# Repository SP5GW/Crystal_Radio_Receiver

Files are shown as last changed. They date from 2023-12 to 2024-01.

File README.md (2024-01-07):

# Crystal Radio Receiver

<p align="center">
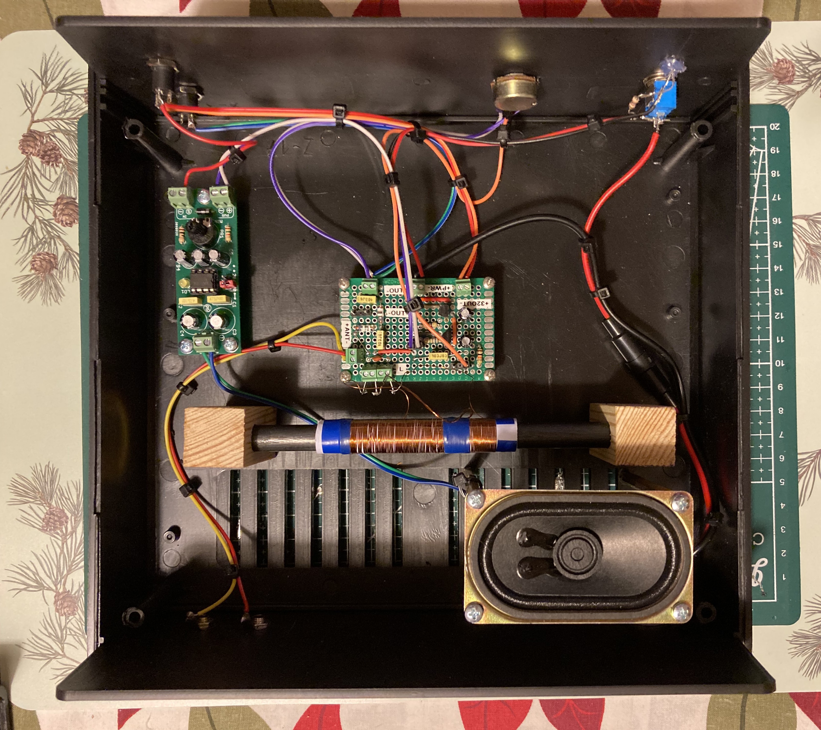
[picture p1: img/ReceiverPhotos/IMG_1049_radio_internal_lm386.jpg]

</p> 

## Design Overview

Implementation of crystal radio in its simplest form does not include active amplifier and that is why can function without external power supply. 

<p align="center">
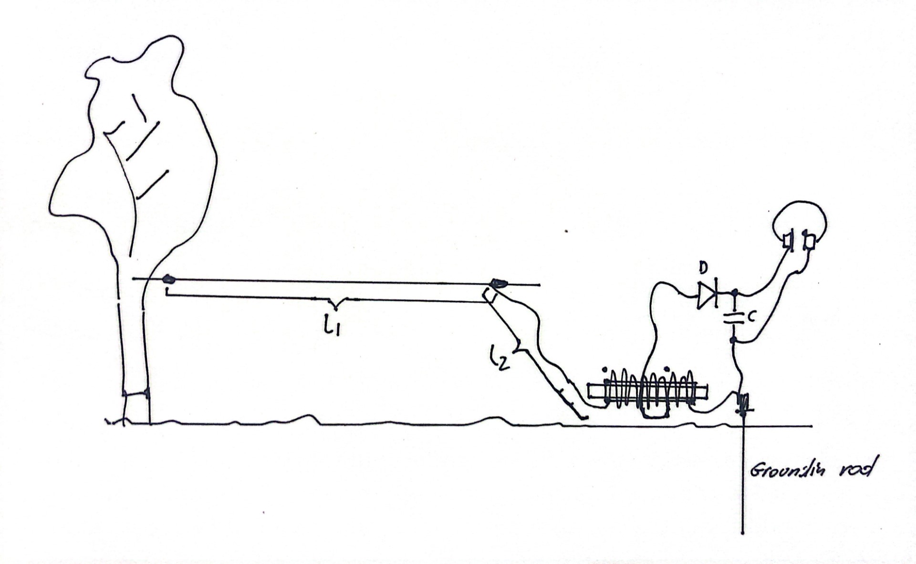
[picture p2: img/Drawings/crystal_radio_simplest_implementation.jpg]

</p>

There are three building blocks of such radio: bandpass filter based on RLC circuit, detector/demodulator stage and high impedance headphones (common today 32ohm headphones can be used as well, but would require amplification stage).

<p align="center">
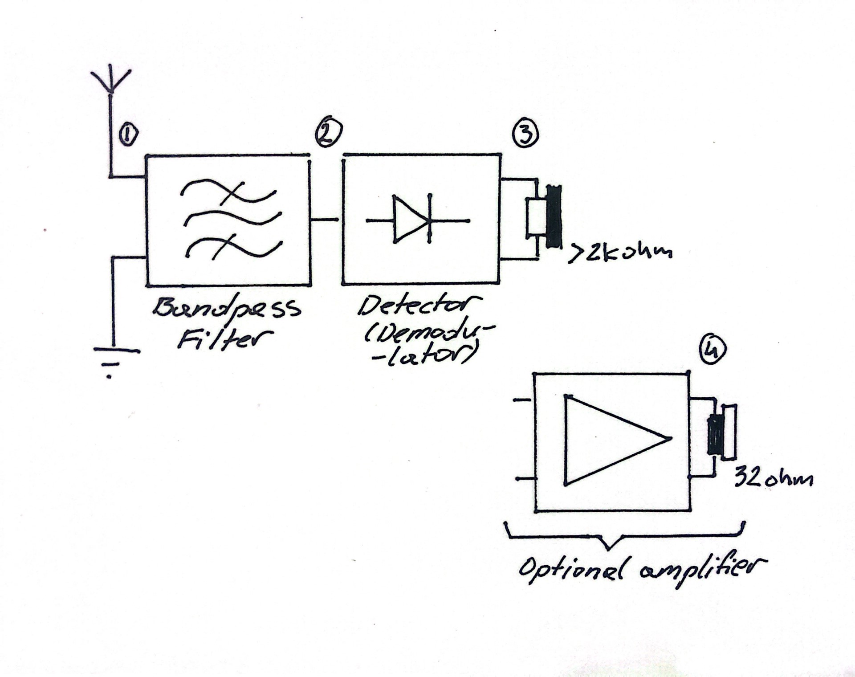
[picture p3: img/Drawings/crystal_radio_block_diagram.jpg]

</p>

Contrary to common believe that crystal radio unit always include RLC parallel resonant circuit, design described here is based on serial resonant RLC circuit consisting of random wire antenna and the coil. Random wire antenna provides capacitance required to form together with the coil serial LC resonant circuit. 

To decrease impact of relatively low detector stage impedance on quality Q of LC circuit, tapped coil is used (autotransformer configuration). 
In ealry designs both tap and also coil itself was often skipped. In such implementation signal level reaching detector stage would be higher (assuming detector input impedance will be higher then the one of coil), but there will be very poor or no selectivity. 

Compromise between output signal strenth and selectivity is a main challange of crystal radio design. 

In discussed circuit, crystal has been replaced with germanium diode. Half-wave rectifier has been also replaced with full rectifier configuration in actual implementation. This however did not lead to any improvments in signal quality or strength since benefit of increased output voltage has been ofsetted by incresed load (x2) put by this type of rectifier on the coil compared to its half wave variant. This is the reason for leaving half wave recifier on all drawings mentioned in this section.

Experiments were made with use of more common Shotkeys diodes, but were not successful (not possible to detect any signals).

Due to relatively high detector output impedance, the use of high impedance headphones or high input impedance amplifier stage is a must.

Capacitor C, which filters out carrier frequency from baseband signal has been left in the design, but its presence did not make any impact on output signal quality.

This type of crystal radio design requires unbalanced antenna i.e. grounding must be of high quality (resistance of 10-100ohm) in order for radio to operate.

Electronic circuit has been inspired by design described by Andrzej Dabrowski OE1KDA in Swiat Radio [1] / Issue 54 of Library of Polish HAM [2] and 
more recent work of Bob Culter N7FKI in ARRL QST magazine [9].

Theory of operation has been predicted during Spice simulations. Details of technical design are based on great work of Berthold Bosch, DK6YY  Crystal Set Analysis [5],  Kenneth A. Kuhn, Crystal Radio Engineering [7] and Johen Bauer, Receiving Antennas for the AM Bands = Loop vs. Vertical Wire [8].

## Design Details

As mentioned earlier in this particular implementation of crystal radio, antenna and the coil form the resonant serial RLC ciruit, which can be modelled as depicted on the drawing below:

<p align="center">
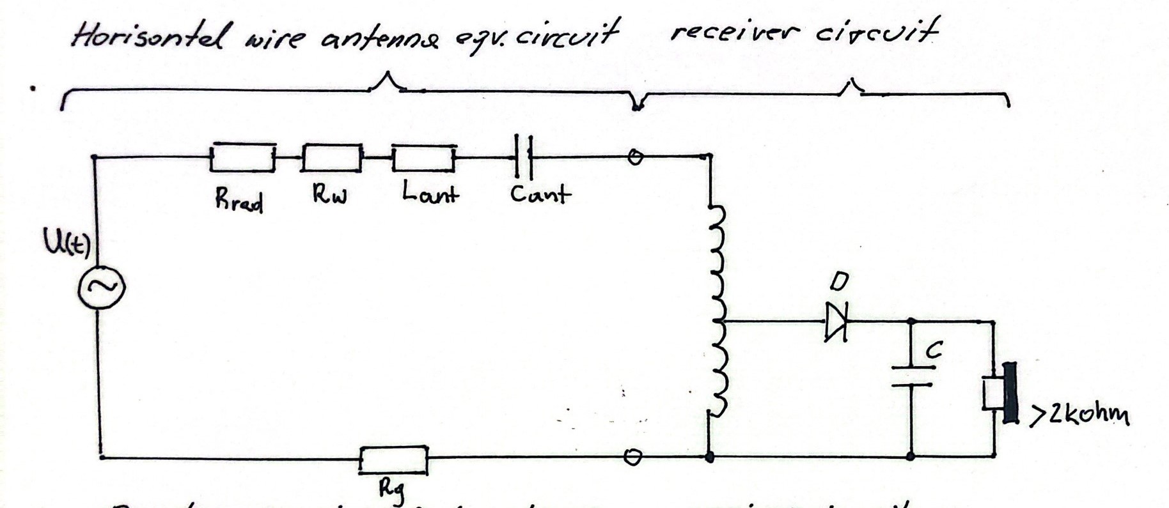
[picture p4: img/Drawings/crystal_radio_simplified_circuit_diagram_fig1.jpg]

</p>

where [7],[8]:
* 	**U(t)** - ideal voltage source - antenna voltage pickup
* 	**Cant** - antenna's serial capacitance - dominating part of antenna's 	reactance if the antenna is shorter than one-quarter wavelength
* 	**Lant** - antenna's serial inductance -  dominating part of antenna's reactance if antenna is  between one-quarter and one-half wavelength at      which capacitive reactance dominates. (at one quarter wavelength antenna is resistive) next quarter wavelength
* 	**Rrad** - The effective radiation resistance associated with the total antenna length. For electrically short antennas this may only be a few ohms but can rise to several tens of ohms as the antenna length approaches one quarter wavelength.
* 	**Rw**   - electrical resistance that is mainly due to the skin effect of the conductor (antenna wire) since the frequency is high
* 	**Rg**   - ground resistance

In case of random wire antenna for long wave reception, antenna's electrical length is typically much smaller then lambda/4 coresponding to received frequency.

In our case the target frequency is f = 225kHz (Polish Radio Warszawa I Broadcast) and coresponding wave length:

$lambda = vf* (c/f)$ 

where:
* **c**  - speed of light in free space: 299 792 458 m/s
* **vf** - velocity factor for cooper wire: 0.95 (radio wave travels in the wire 5% slower then in free space)
* **f**  - broadcast frequency

hence:

* lambda (free space) = 1332,4m (lambda/4=333,1)
* lambda (cooper wire) = 0.95 * 1332,4 = 1265,8m (lambda/4 = 316.5m)

So the total length of our antenna cable (including wire leading to the radio) is 25m, which is shorter then lambda/4 for both free space and cooper wire.

Above means that antenna's reactance is purly capacitive  and **Lant** can be omited from the simplified model of used antenna design.

Due to the short length of antenna cable, wire resistance **Rw** can also be skipped.

Radiation resistance **Rrad** for electrically short antennas is typically equal to a few ohms (**Rrad** can rise to several tens of ohms as the antenna length approaches one quarter wavelength).

According to the property of reciprocity every antenna can be used to both transmit and receive electromagnetic radiation. That is why, radiation resistance can be understood as equivalent ohmic resistor, which "disipates" power delivered from the transmitter to the antenna. Power disipated in this case leaves antenna in the form of electromagnetic radiation. [8]

Ground Resistance **Rg** is dominant in the model and can be less then 10 ohms in case of excellent grounding and up to 100ohms and more when grounding is poor.

Based on above analysis and actual measurements summarized in table below it becomes apparent that random wire antenna's equivalent circuit can be simplified to include only capacitance **Cant** and **Rant** equal to Rg + Rrad.

<p align="center">
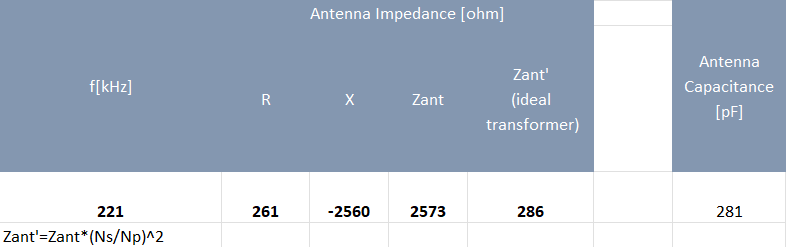
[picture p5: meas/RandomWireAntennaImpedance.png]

</p>

Equivalent circuit reflecting above assumptions:

<p align="center">
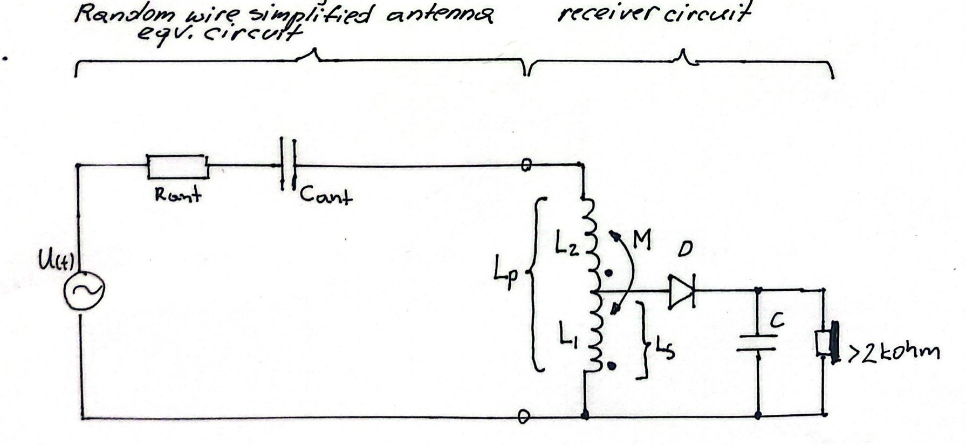
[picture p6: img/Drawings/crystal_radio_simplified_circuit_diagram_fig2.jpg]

</p>

The frequency of serial resonance for such circuit can be calculated as:

$fr=\frac{1}{2*\pi*\sqrt{Lp*Cant}}$

where **Lp** is the inductance of the coil expressed as:

$Lp=L1+L2+2M$

**Lp**, **L1** and **L2** can be directly measured with NanoVNA or another inductance meter while M can be calculated as:

$M=(Lp-L1-L2)/2$

For simulation purpuses it is useful to also calculate coupling coefficient **k** as:

$k=M/\sqrt{L1*L2}$

Actual measurements were summarized below:

<p align="center">
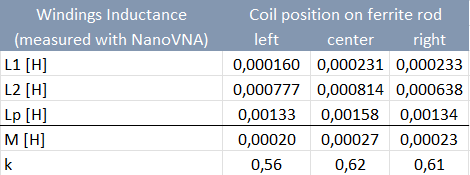
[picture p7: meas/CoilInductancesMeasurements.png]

</p>

As can be seen above, the tap on the coil does not impact resonance frequency, however level of magnetic coupling shall be taken into account when calculating inductance value of the coil i.e. total inductance is higher then the sum of inductances of each section of the coil measured separately.

For the coil centrally positioned on the ferrite rod resonance frequency is:

$fr=\frac{1}{6.28*\sqrt{1.58 \times 10^{-3} \times 281 \times 10^{-12}}}=238.72kHz$

It was not possible to increase coil's inductance **Lp** by repositioning it on the rod. That is why 47pF additional capacitor was added in parallel to **Lp** to bring resonance frequency **fr** to desired 225KHz. 
See Spice simulation below:

<p align="center">
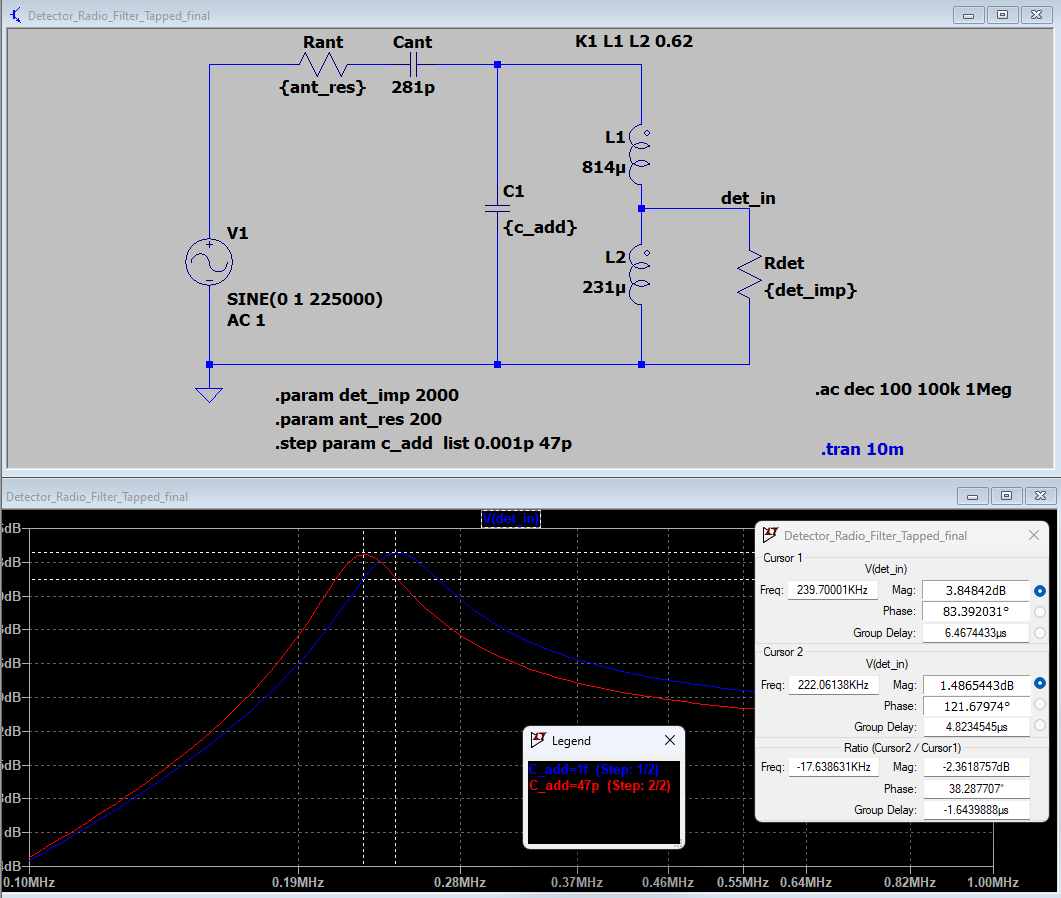
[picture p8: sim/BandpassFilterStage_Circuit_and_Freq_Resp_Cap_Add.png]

</p>

Input impedance of the detector stage together with antenna system resistance **Rant** directly impacts Q-factor of RLC resonance circuit.
This is the reason for both the need for best quality grounding (i.e. lowest possible **Rg**) 

<p align="center">
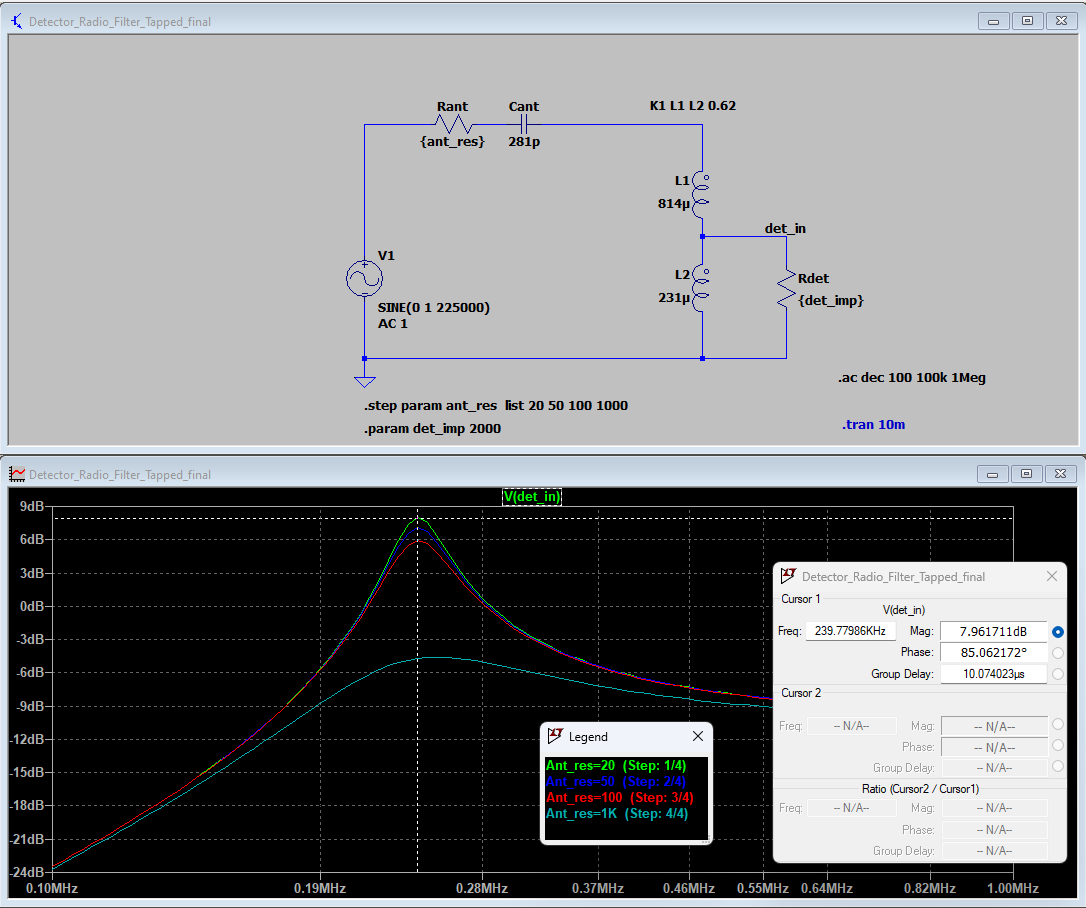
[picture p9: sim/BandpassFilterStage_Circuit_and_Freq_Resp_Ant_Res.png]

</p>

and also the use of autotransformer to connect detector stage to the RLC circuit.

<p align="center">
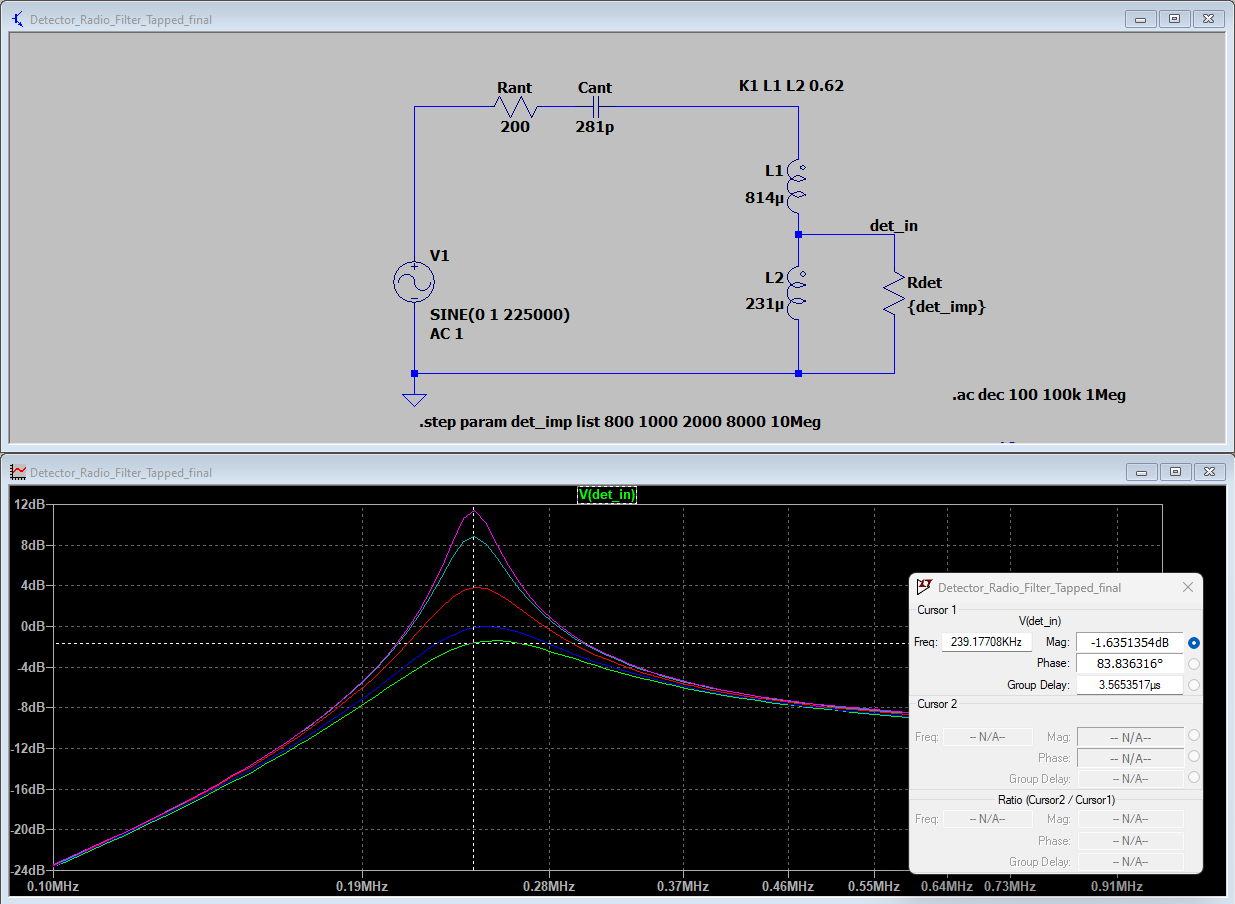
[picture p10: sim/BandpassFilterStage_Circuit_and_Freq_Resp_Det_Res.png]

</p>

Autotransformer transforms input impedance of the detector **Rdet** to larger value of **Rdet'**. In situation where reactace of **XL1** is much greater then **Rdet'** impedance transformation follows the formula for ideal transformer. 

$Rdet'/Rdet=N^2$ where $N=Np/Ns=sqrt(Lp/Ls)$

In case of this design however impedance transformation is "weakened" by the fact that **XL1**  is of similar value as transformed impedance of the detector stage (for fr=225kHz the impedance XL1=2.5kohm). For lower values of **Rdet**, detectors input impedance shounts also **XL1**, which also leads to slight shift upwords of the circuit's resonance frequency.

When detector stage is connected to the tap of the coil the RLC Q-factor decreases more then twice (i.e. decrease from 11.6 to 4.6), which coresponds to circuit's bandwidth increase from about 20kHz to 51kHz. This selectivity decrease makes design less dependent on exact value of antenna capacitance. 
As can be seen on the picture below the AM signal from Polish Radio occupies only about 12kHz in bandwidth (with center frequency fr=225Khz)

<p align="center">
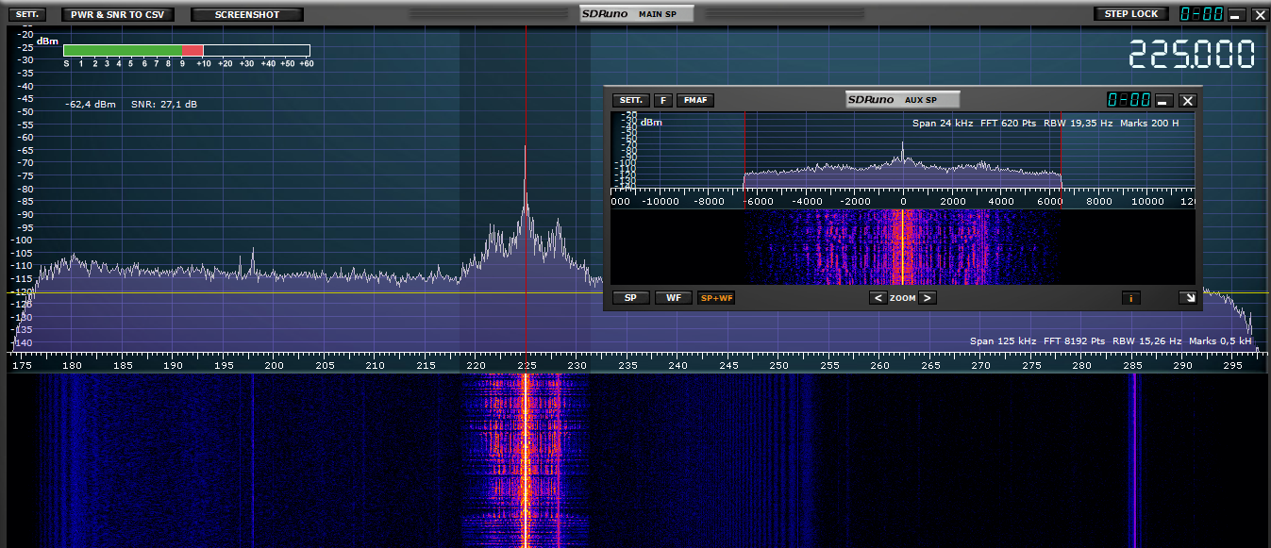
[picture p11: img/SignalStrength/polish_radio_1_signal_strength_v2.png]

</p>

As mentioned earlier attempt to replace Germanium AAP153 diode with Shotkey equivalent was not successful. 

Use of full wave rectifier in the design does not lead to increase signal volume compared to scenario when half wave rectifier is used. This is due to twice as low input impedance of full wave rectiver compared to its half wave variant.

When no external power source is available (aplifier based on T1/T2 is not used), high impedance headphones are needed. This is due high impedance of detector output.

Aplifier based on T1/T2 allows for use of regular 32ohm headphones, but this stage requires external power supply. To decrease amount high frequencies in signal reaching headphones RC low pass filter has been added in front of transistor aplification stage.

<p align="center">
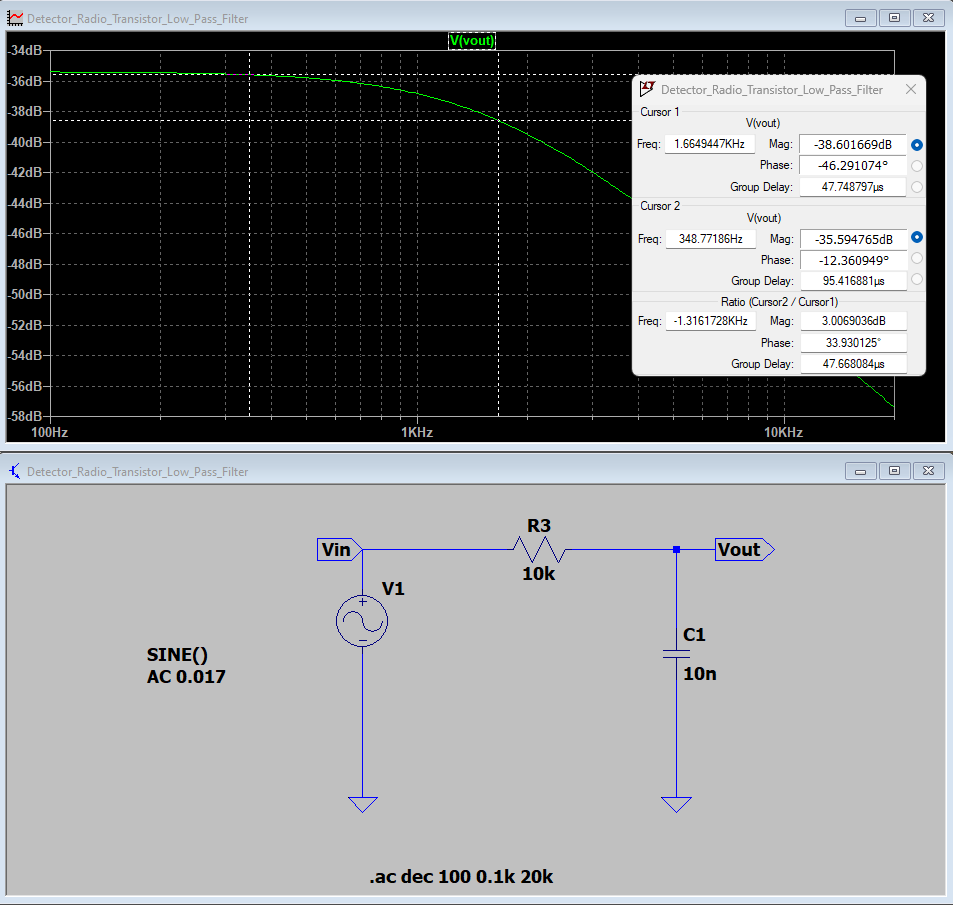
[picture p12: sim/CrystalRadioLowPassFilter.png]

</p>

Full Crystal Radio simulation circuit can be seen below:

<p align="center">
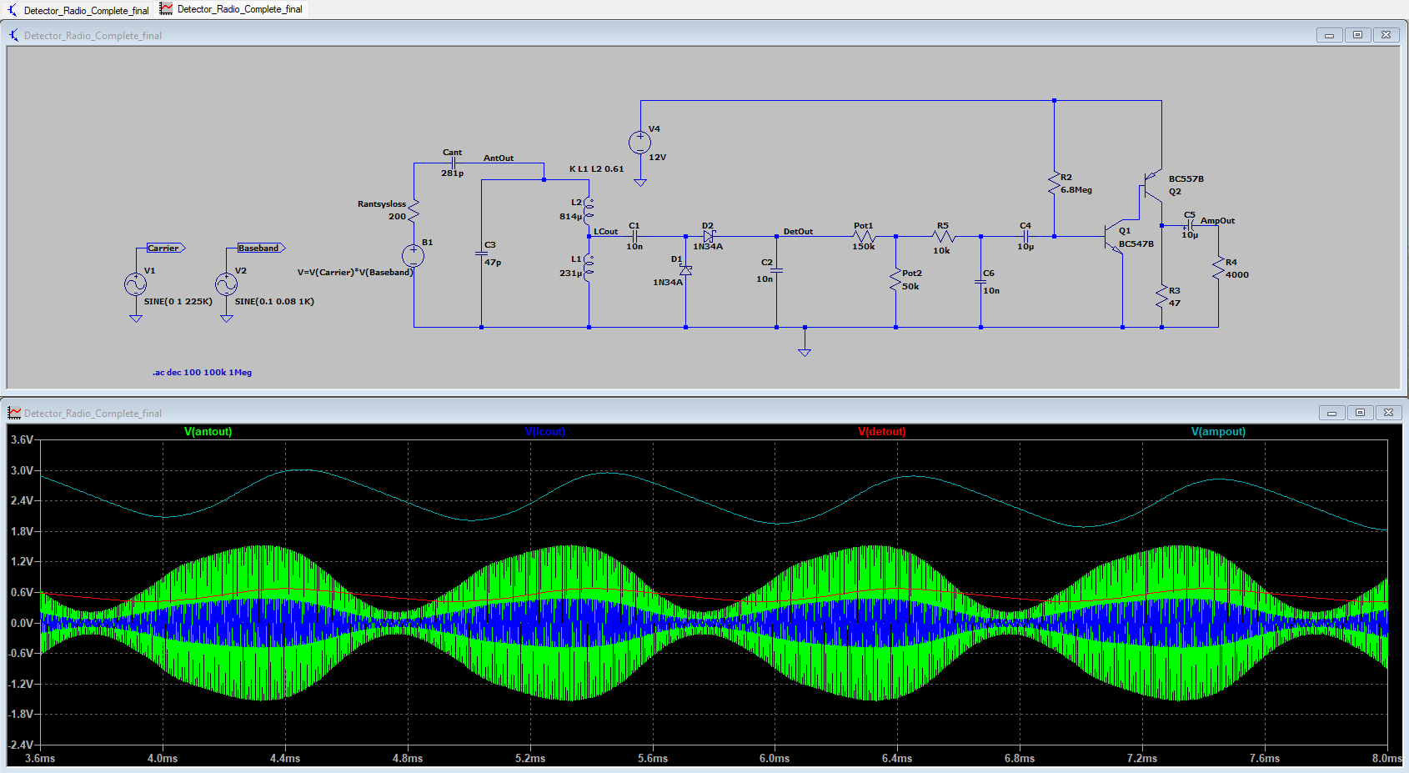
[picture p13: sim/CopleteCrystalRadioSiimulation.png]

</p>

## Implementation

<p align="center">
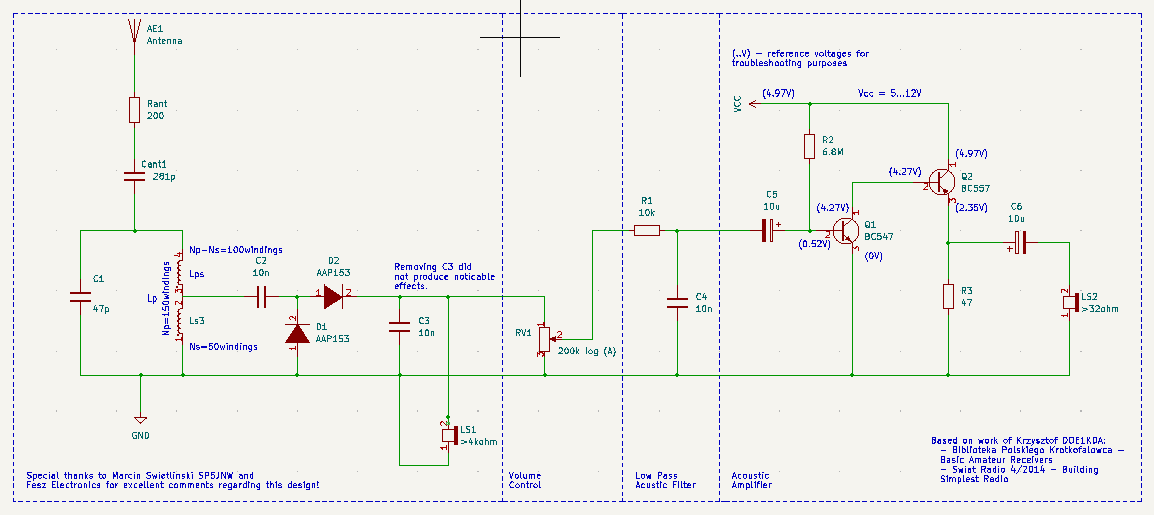
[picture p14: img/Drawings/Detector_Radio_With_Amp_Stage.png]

</p>

Design of the coil is critical for entire circuit to work. This element has been made using 0.35mm emalia coated wire. Windings were made on paper tube put on ferrite rod from old radio receiver. Position of the coil can be adjusted by sliding to both sides of the rod allowing for limited resonance frequency adjustment. Tuning is made by the ear for strongest acusting signal. Coil winding configuration: 50 windings - 5cm long tap - 100 windings. All windings are made in the same direction. To bring resonance frequency closer to 225kHz, the 47pF ceramic capacitor was put parallel to the coil. Decreasing this capacitor to smaller value did not increase signal level at detector output, capacitor increase led to decrease in volume, which suggest that selected capacitance value is optimal for this particular design.

Mechanical mounting of the coil can be difficult. The most elegant would be to 3D print required moutning brackets. In this case simpler wooden mounts were used purely due to lack 3D printer access. See pictures below for details of coil mounting method:

<p align="center">
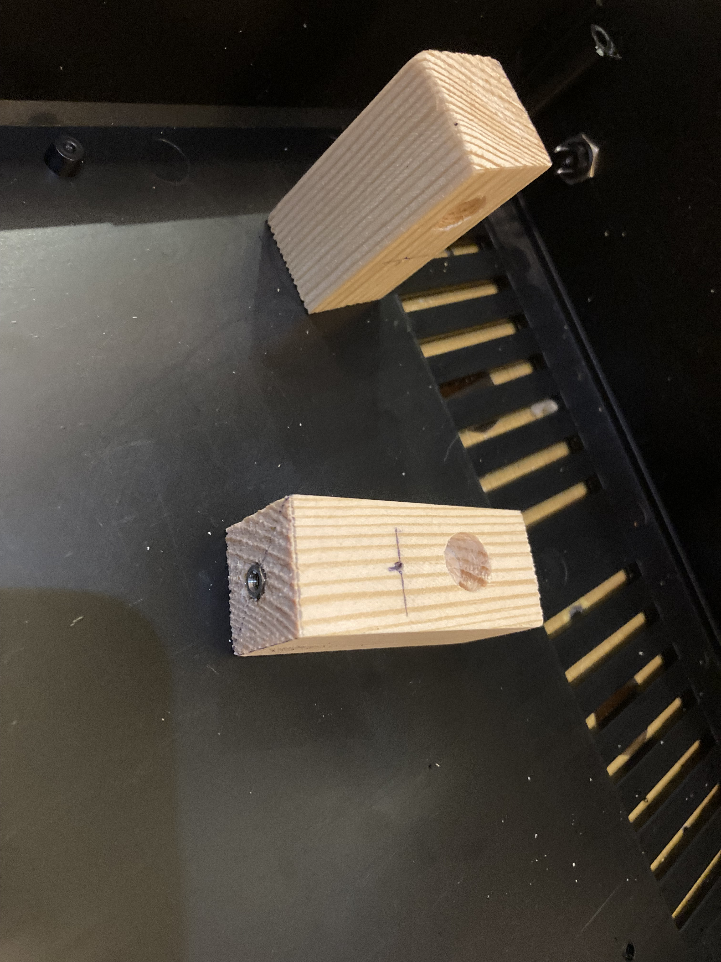
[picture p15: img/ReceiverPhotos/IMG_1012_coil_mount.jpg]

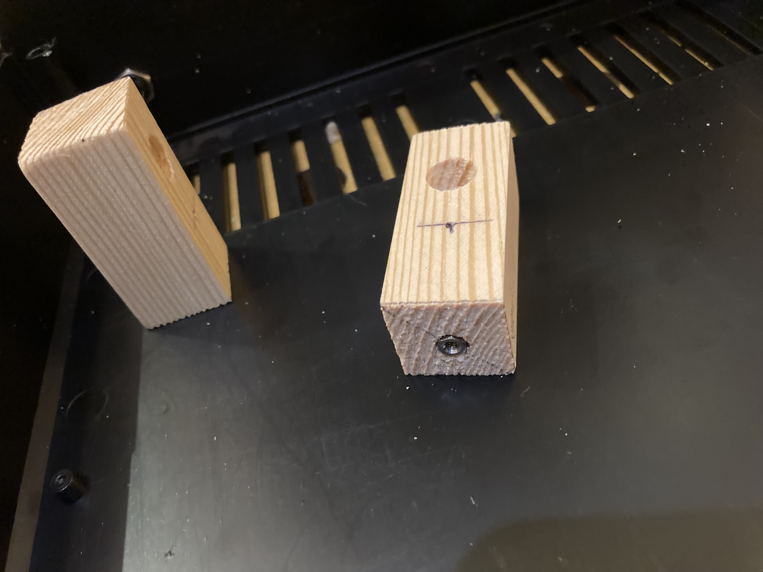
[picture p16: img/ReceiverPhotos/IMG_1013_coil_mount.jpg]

</p>

<p align="center">
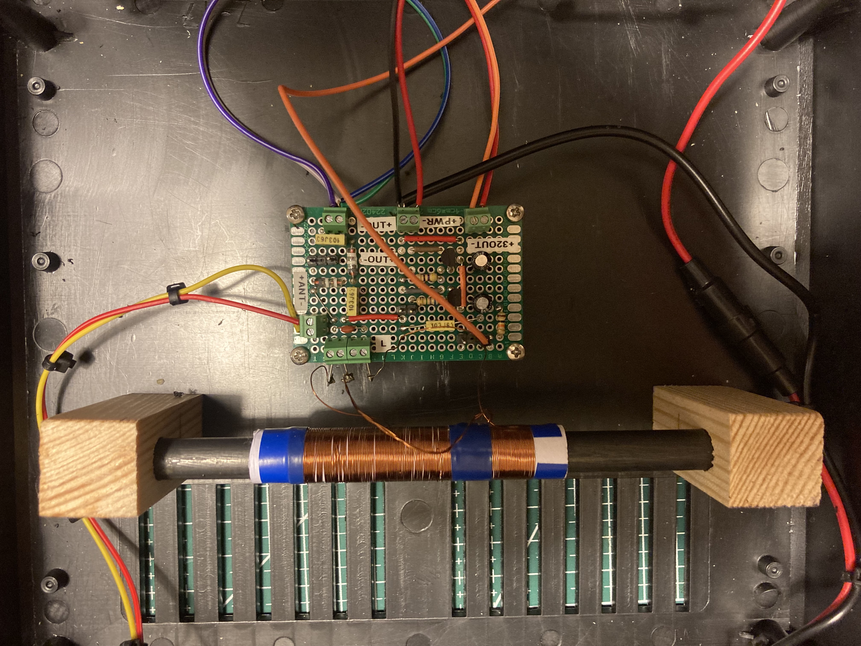
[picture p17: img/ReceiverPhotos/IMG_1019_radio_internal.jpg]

</p>

Special thanks  to SP5JNW and Fesh Electronics for great explanation of theory behind LC and autotransformer design [3] and time taken to anwser my emails.

Quality of earthing is critical for crystal radio to operate at all!

To increase signal output and allow for use of 32ohm modern headphones simple 2 transistor amplifier has been added.

In actual design another amplification stage based on LM386 circuit was added (AVT794 kit). LM386 is driven directly from the output of transistor aplifier and connects to 8ohm 5W speaker.

Acustic signal at the output of the detector stage is biased towards higher frequencies. To correct for it low-pass filter is introduced together with volume control. 

Measurements of actual signal levels can be seen below:

AM Modulated Signal level at coil tap (input of the detector):

<p align="center">
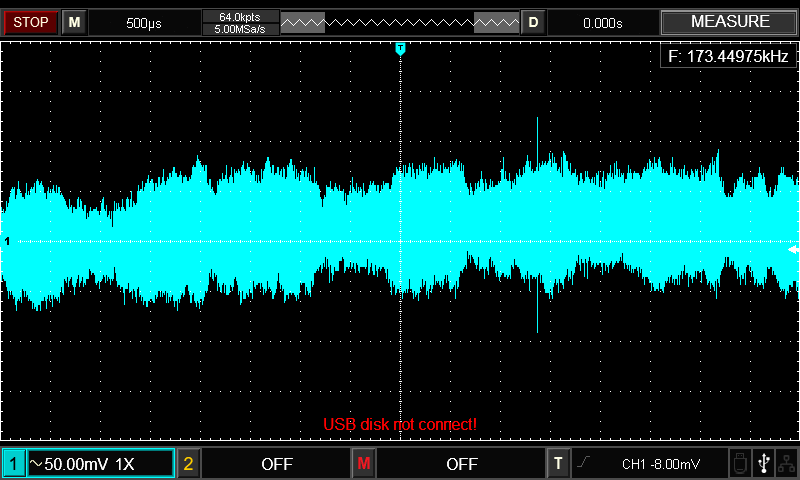
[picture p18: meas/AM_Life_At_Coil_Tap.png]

</p>

Demodulated signal at the output of the detector:

<p align="center">
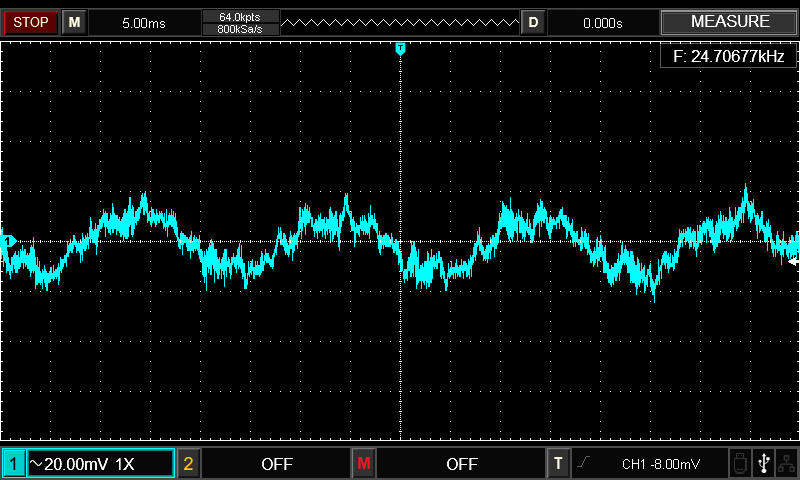
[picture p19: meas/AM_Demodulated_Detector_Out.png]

</p>

Signal at the output of transistor amplifier (volume control not set to maximum):

<p align="center">
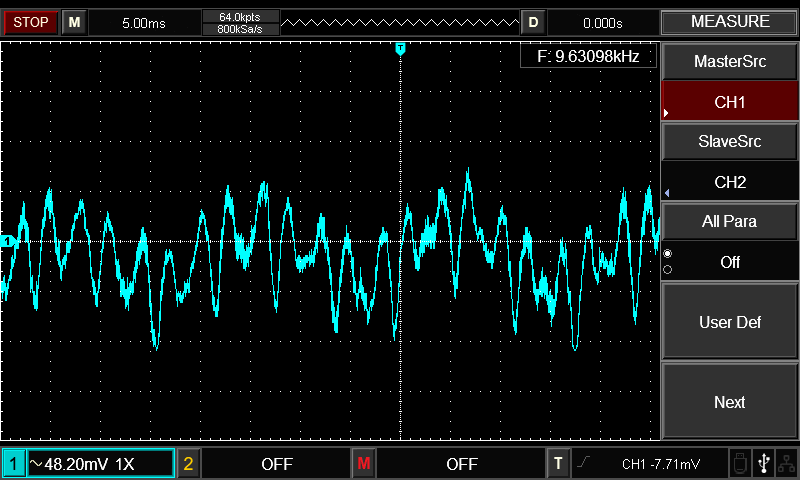
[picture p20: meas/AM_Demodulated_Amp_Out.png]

</p>

Fully finished crystal radio including LM386 amplifier:

<p align="center">

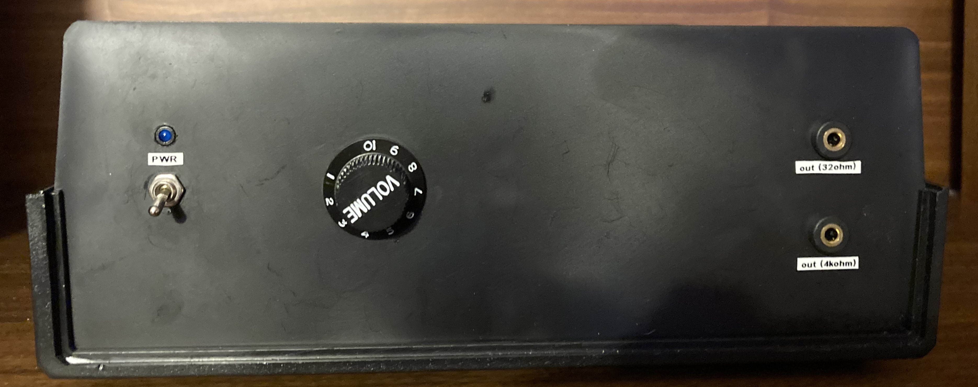
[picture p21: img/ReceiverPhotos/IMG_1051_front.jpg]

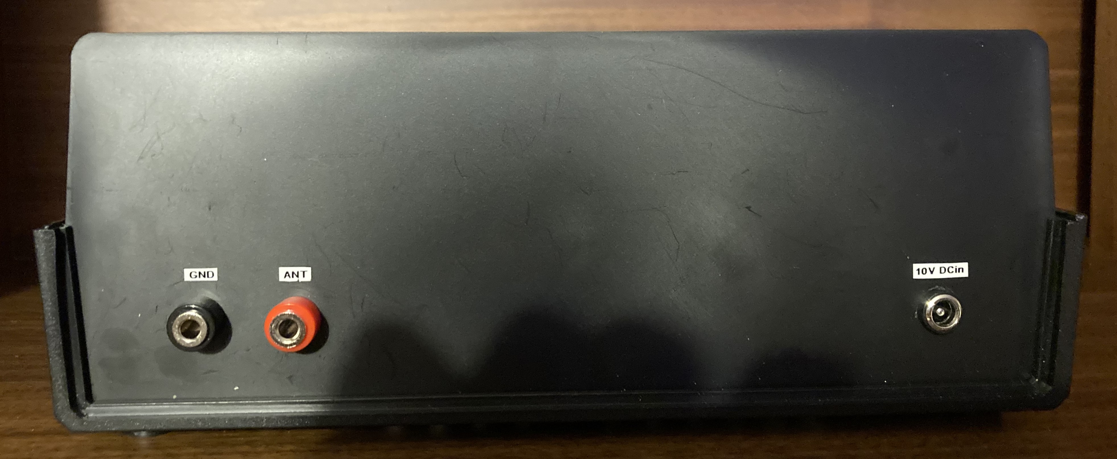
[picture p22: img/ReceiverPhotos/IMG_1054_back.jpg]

</p>

## Resources

[1] Swiat Radio 4/2014, Building Simplest Radio, http://www.swiatradio.com.pl/virtual/

[2] Library of Polish Radio Amateur, Issue 54: Simple Amateur Receivers, Part I, https://bpk.pzk.org.pl/

[3] Parallel Tuning Circuit by Marcin Swietlinski SP5NJW, https://sem.pl/sp5jnw/technika/technika.html

[4] LTspice tutorial - Modeling transformers, https://youtu.be/muUwe8X51oY?si=RbQENTwcjtkwcD5b

[5] Crystal Set Analysis,Berthold Bosch, DK6YY, https://www.pe2bz.philpem.me.uk/Comm/-%20Receivers/-%20Crystal/Info-902-MiscCrystalHints/Misc/analysis.htm

[6] Magnetically coupled circuits, Yahia Baghzouz, University of Nevada, http://www.ee.unlv.edu/~eebag/AlexanderCh13.pdf

[7] Crystal Radio Engineering, Kenneth A. Kuhn, https://www.kennethkuhn.com/students/crystal_radios/

[8] Receiving Antennas for the AM Bands = Loop vs. Vertical Wire, Johen Bauer, https://www.radiomuseum.org/forumdata/upload/am_receiving_antennas_rel.pdf

[9] High Sensitivity Crystal Set, Bob Culter, N7FKI, QST January 2007

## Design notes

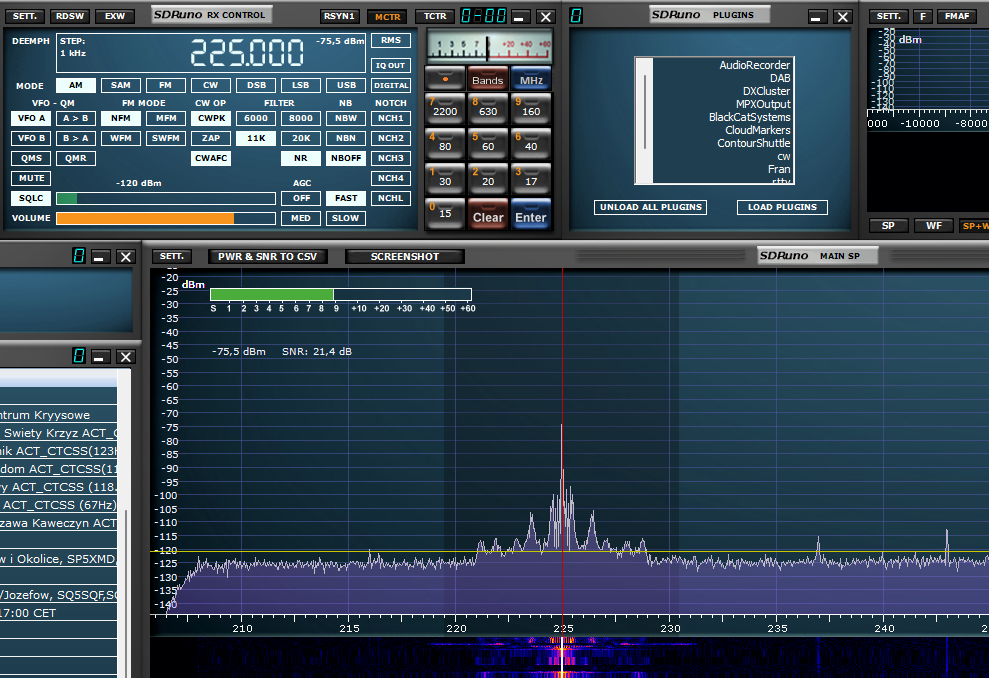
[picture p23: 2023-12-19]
img/SignalStrength/Zrzut ekranu 2023-12-16 172111_signal_spectrum.png

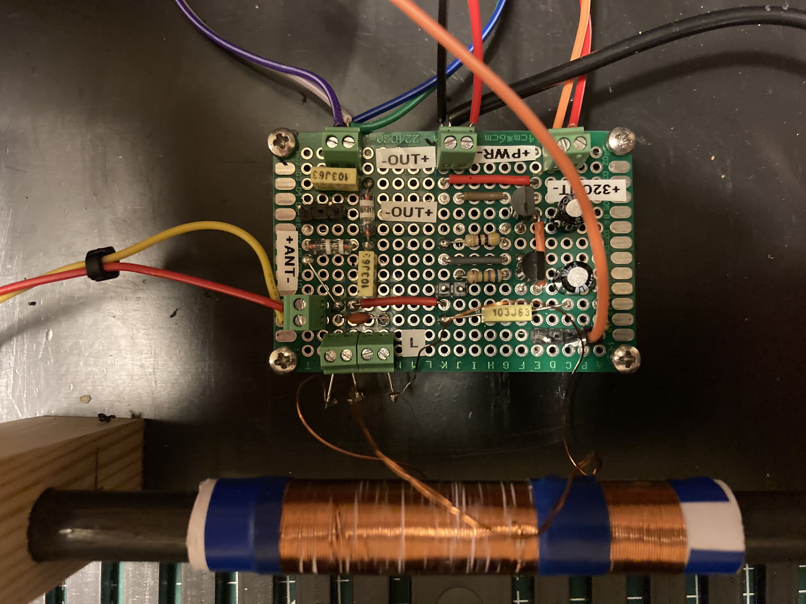
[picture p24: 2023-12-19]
img/ReceiverPhotos/IMG_1021_radio_internal.jpg

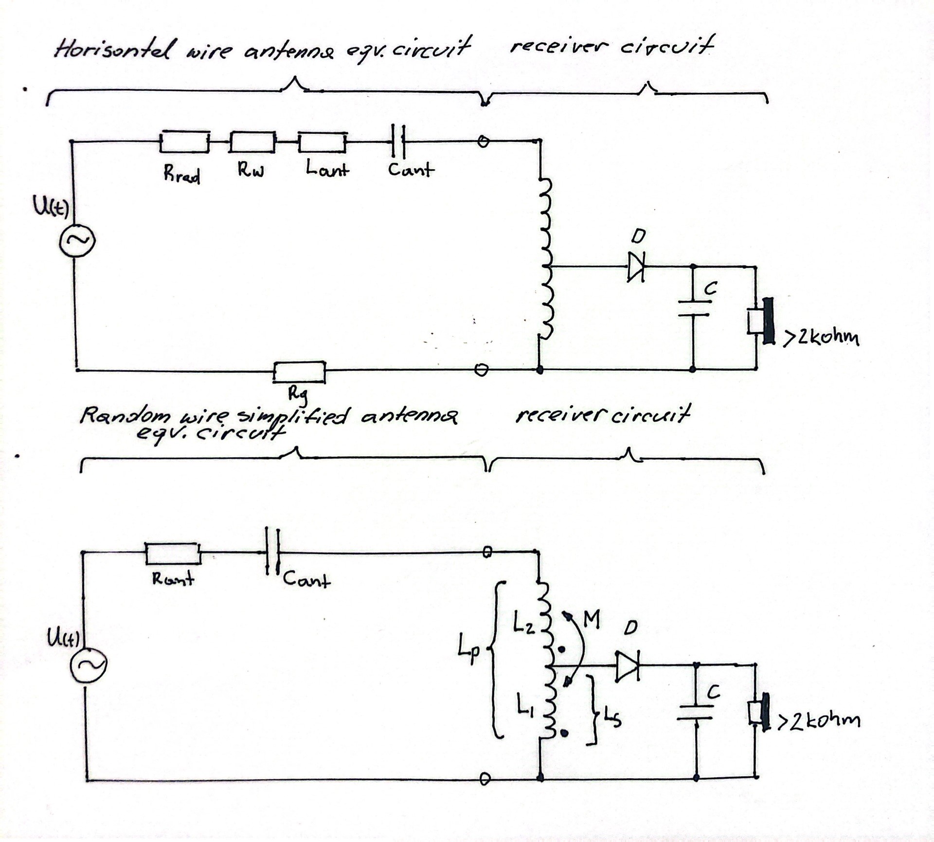
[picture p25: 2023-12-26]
img/Drawings/crystal_radio_simplified_circuit_diagram.jpg

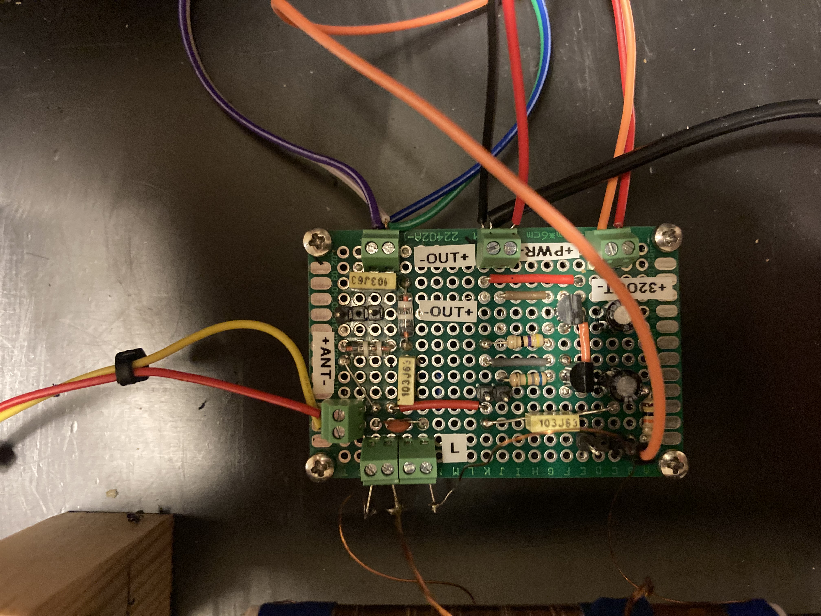
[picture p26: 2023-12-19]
img/ReceiverPhotos/IMG_1020_radio_internal.jpg

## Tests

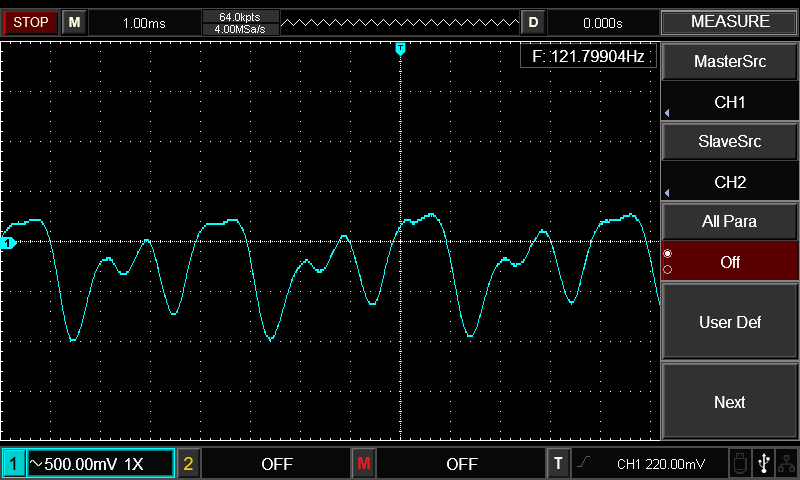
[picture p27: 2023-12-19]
img/Measurements/Max_Amplified_Output_Signal.png

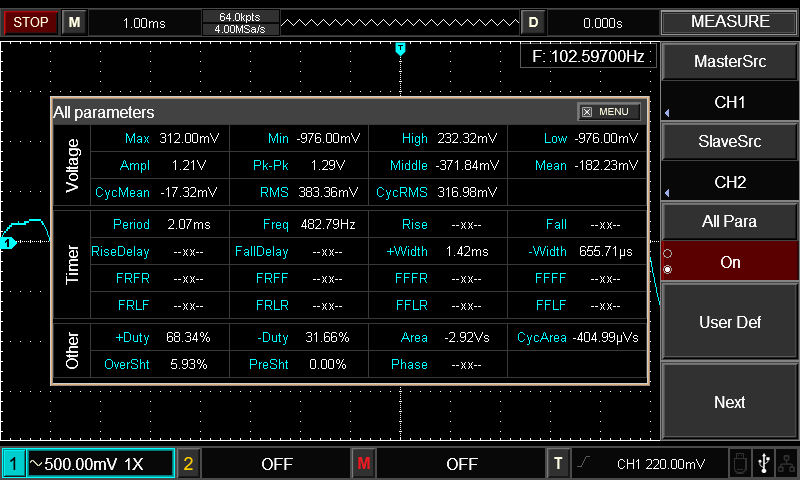
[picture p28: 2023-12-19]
img/Measurements/Max_Amplified_Output_Signal_Measurements.png

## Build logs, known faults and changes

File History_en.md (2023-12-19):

## Based on information placed in front of the building of
## Radio Broadcasting Centre (RCN) in Solec Kujawski

Polish Radio
Radio Broadcasting Centre in Solec Kujawski

It is one of the most modern central transmitting stations in Europe with a output power of 1000kW, 
emitting The First Programme of the Polish Radio on long wave 225kHz frequency since 4 September 1999. 
Its range covers the whole of Poland and partly neighbouring countries and, in favourable conditions, 
further European countries.

<p align="center">
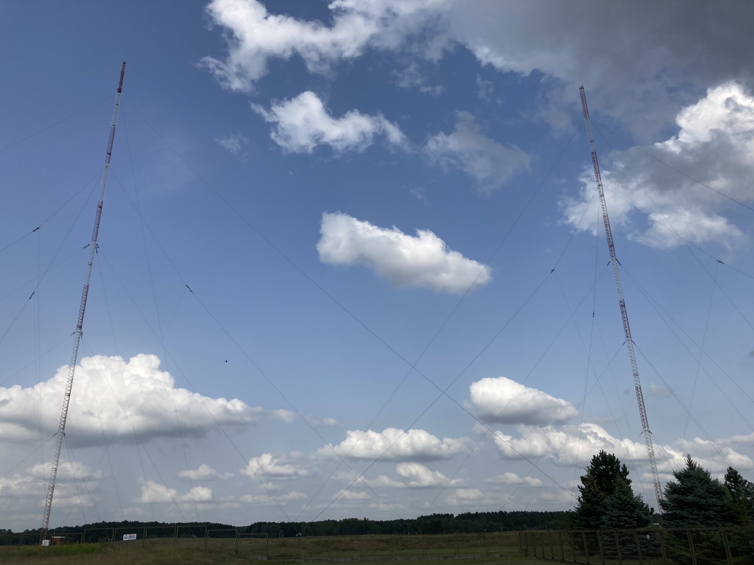
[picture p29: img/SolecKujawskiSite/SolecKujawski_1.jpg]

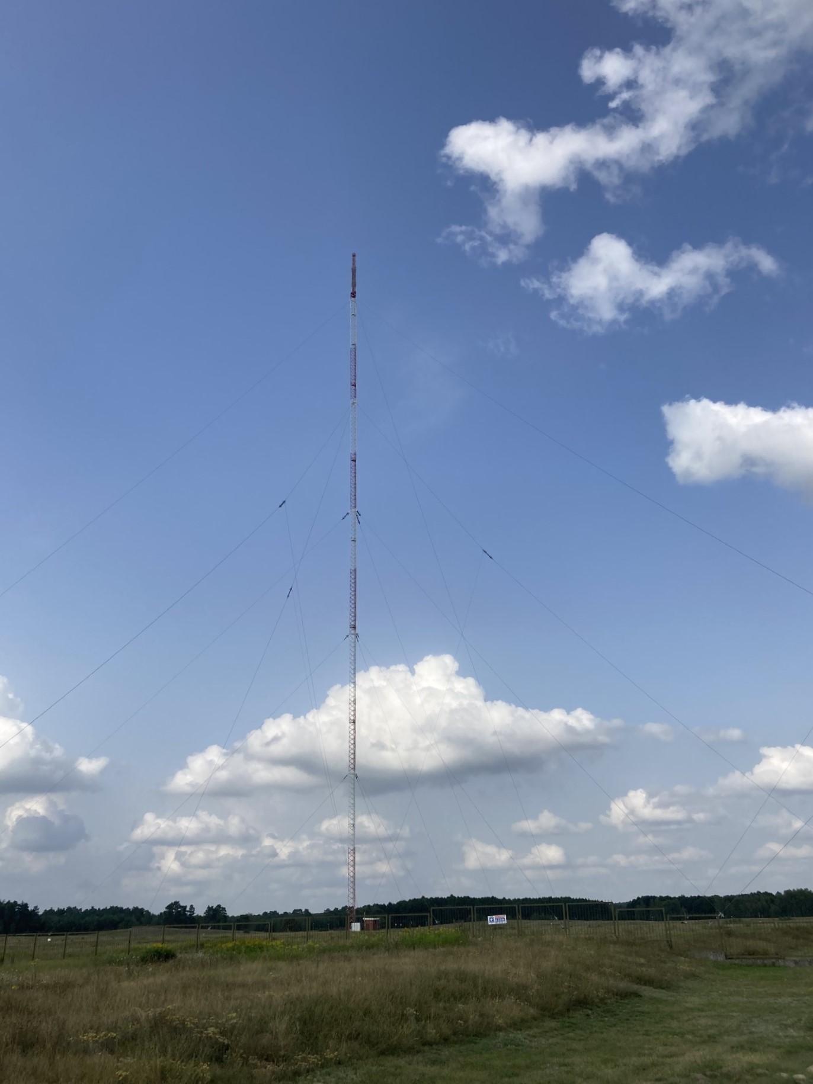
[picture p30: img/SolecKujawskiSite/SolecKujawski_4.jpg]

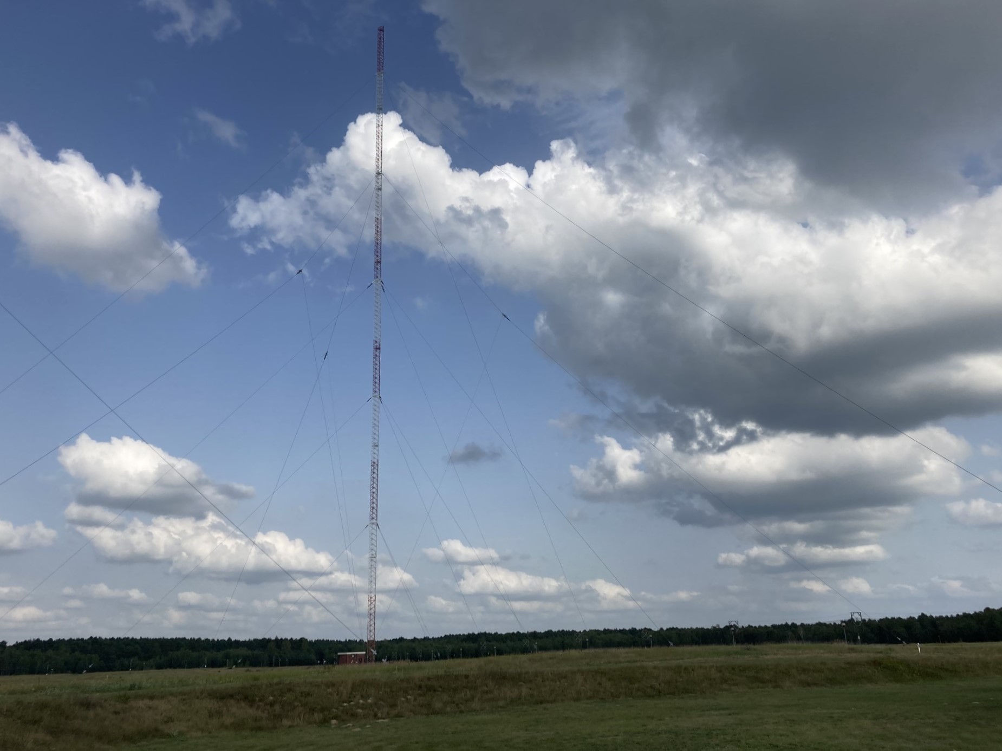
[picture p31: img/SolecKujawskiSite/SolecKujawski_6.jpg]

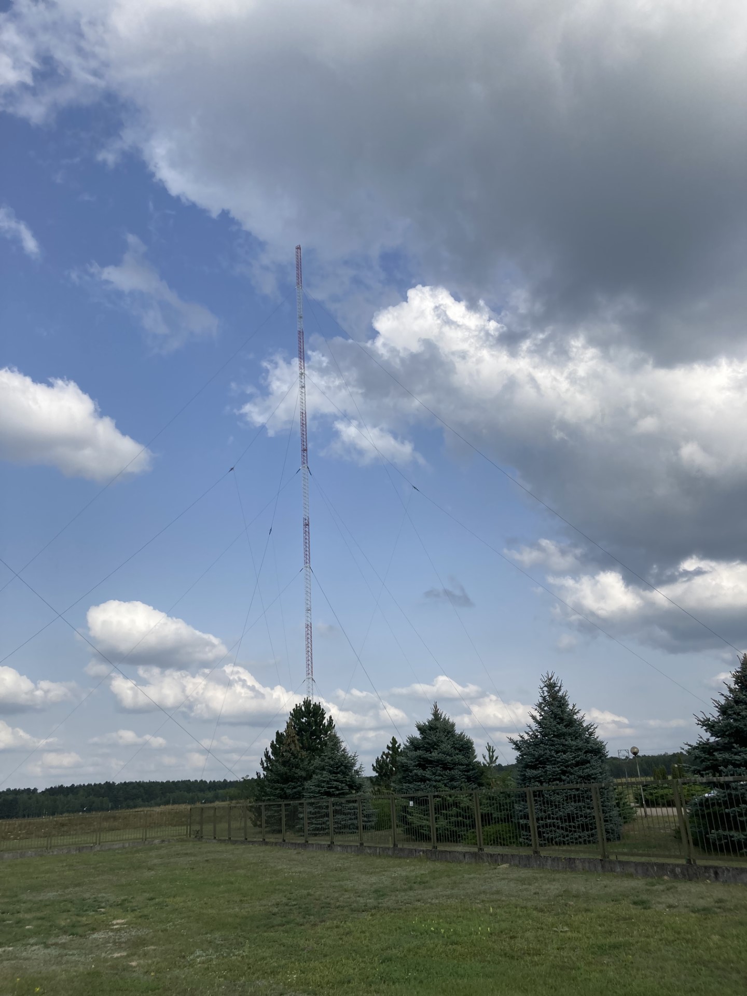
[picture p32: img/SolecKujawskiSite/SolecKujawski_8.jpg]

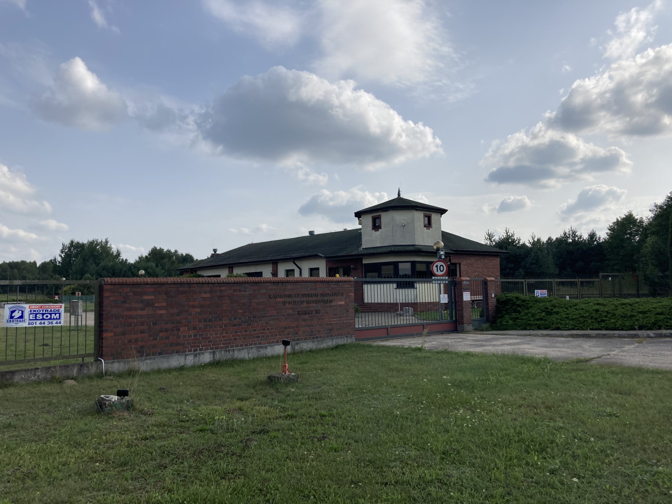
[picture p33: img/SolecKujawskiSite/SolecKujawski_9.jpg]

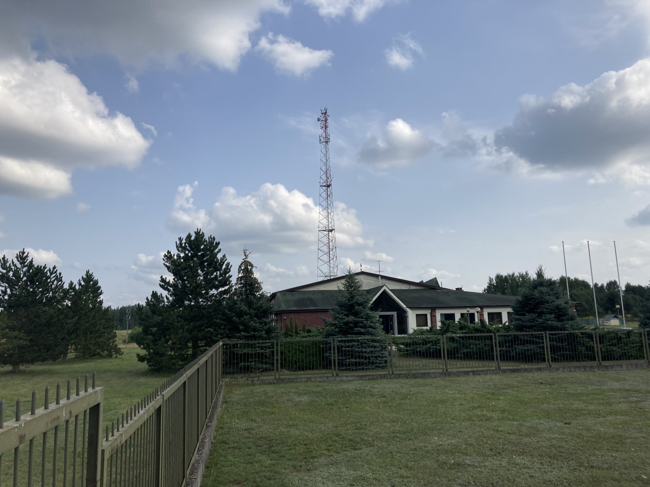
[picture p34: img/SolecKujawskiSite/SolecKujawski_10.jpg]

</p>

A full solution provider of the latest generation of broadcasting equipment and antenna system
is the French company THOMCAST.

Solid-state transmitter with guaranteed energy efficiency of 88%, consists of 
three blocks and a combiner, so it is also possible to work on two blocks
with the third one under maintenance, which significantly increases the reliability of the 
emissions. 

In order to improve the efficiency of the transmitter's operation, a dynamic 
DCC carrier wave level adjustment is used.

Antenna system, with maximum radiation in the south-east direction,
consists of two quarter-wave masts with a height of 230 and 289 meters and an earthing system, 
which act as electromagnetic counterpoise. The masts are held vertically by five levels 
guying wires, made of steel ropes with a diameter of 40mm.

The high-frequency energy from the transmitter is transmitted via a wire coaxial line 
(feeder) and then via the penultimate level of guy ropes to the masts.
The highest non-insulated level of guys, galvanically connected to the ground, is the 
effective protection against lightning.

From 2015 we will start digital broadcasting of Polish Radio programmes in DAB+ standard
to the area of the Kuyavian-Pomeranian Voivodeship.

The RCN area is 75 hectares and is sorrounded by 4.5 km long fence, 
which constituted the border zone of electromagnetic radiation.

The maximum deviation of the top of the mast in strong winds is 1.5m.
Weight of masts: 304 tons.

Time to climb to the top of the mast by well-conditioned person is: 1 hour.

Coverage map and signal level registered at Otwock near Warsaw:

<p align="center">
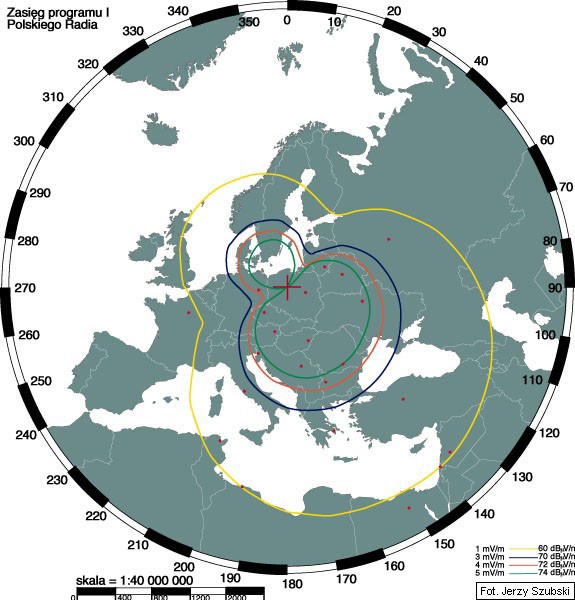
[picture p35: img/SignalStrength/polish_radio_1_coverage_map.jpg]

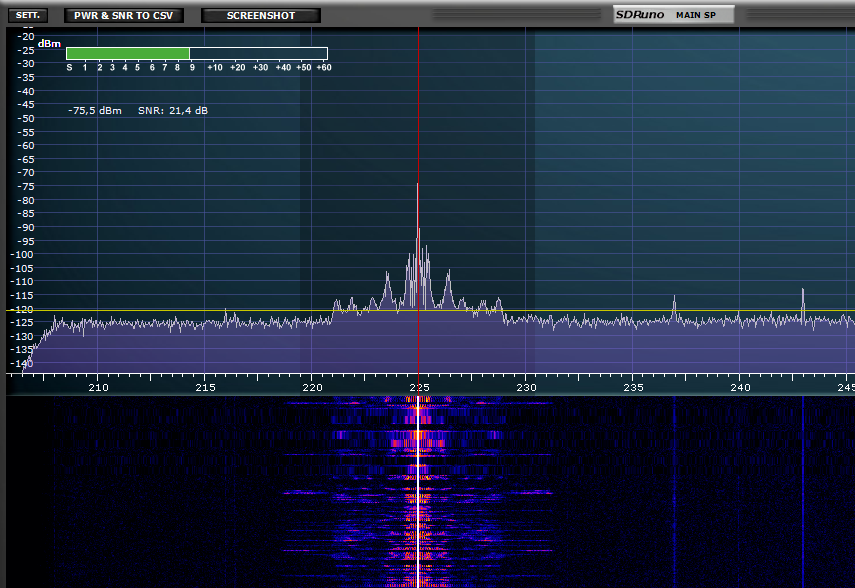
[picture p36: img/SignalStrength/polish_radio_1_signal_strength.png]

</p>

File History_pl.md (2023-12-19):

## Na podstawie informacji umieszczonej przed budynkiem 
## Radiowego Centrum Nadawczego (RCN) w Solcu Kujawskim

Polskie Radio
Radiowe Centrum Nadawcze w Solcu Kujawskim

To jedna z najnowocześniejszych w Europie centralna stacja nadawcza o mocy 1000kW, 
emitująca od 4 września 1999 r., na falach długich sygnał o częstotliwości 225kHz, 
Program Pierwszy Polskiego Radia. Swym zasięgiem obejmująca całą Polskę i częściowo
kraje sąsiadujące, a przy sprzyjających warunkach dalcze kraje europejskie.

<p align="center">






</p>

Kompleksowym dostawcą aparatury nadawczej najnowszej generacji i systemu antenowego
jest francuska firma THOMCAST.

Półprzewodnikowy nadajnik o gwarantowanej sprawności energetycznej 88%, składa się z 
trzech bloków i sumatora, dzięki czemu możliwa jest również praca na dwóch blokach
przy trzecim znajdującym się w konserwacji, co wznacznym stopniu zwiększa niezawodność 
emisji. 

Dla poprawy efektywności pracy nadajnika, zastosowany został system dynamicznej 
regulacji poziomu fali nośnej DCC.

System antenowy, o maksymalnym promieniowaniu w kierunku południowo-wschodnim,
tworzą dwa ćwierćfalowe maszty o wysokości 230 i 289 metrów oraz uziemnienie, będące
przeciwagą elektromagnetyczną. Maszty utrzymywane są w pionie przez pięć poziomów 
odciągów, wykonanych z lin stalowych o średnicy 40mm.

Energia wysokiej częstotliwości z nadajnika przekazywana jest drutową linią współosiową 
(fiderem), a następnie za pośrednictwem przedostatniego poziomu odciągów do masztów.
Najwyższy nieizolowany poziom odciągów, galwanicznie połączony z ziemią, stanowi 
skuteczną ochronę przed wyładowaniami atmosferycznymi.
Od 2015 roku rozpoczniemy cyfrową emisję programów Polskiego Radia w standardzie DAB+
na obszar województwa kujawsko-pomorskiego.

Teren RCN o powierzchni 75ha, ogrodzono płotem o długości 4.5km, stanowiącym granicę
strefy pośredniej promieniowania elektromagnetycznego.

Maksymalne odchylenie szczytu masztu przy silnym wietrze wynosi 1.5m.
Waga masztów: 304 tony.

Czas wejścia na szczyt masztu wysportowanego człowieka: 1 godzina

Mapa zasięgu oraz poziom sygnału zarejestrowany w Otwocku pod Warszawą:

<p align="center">


</p>

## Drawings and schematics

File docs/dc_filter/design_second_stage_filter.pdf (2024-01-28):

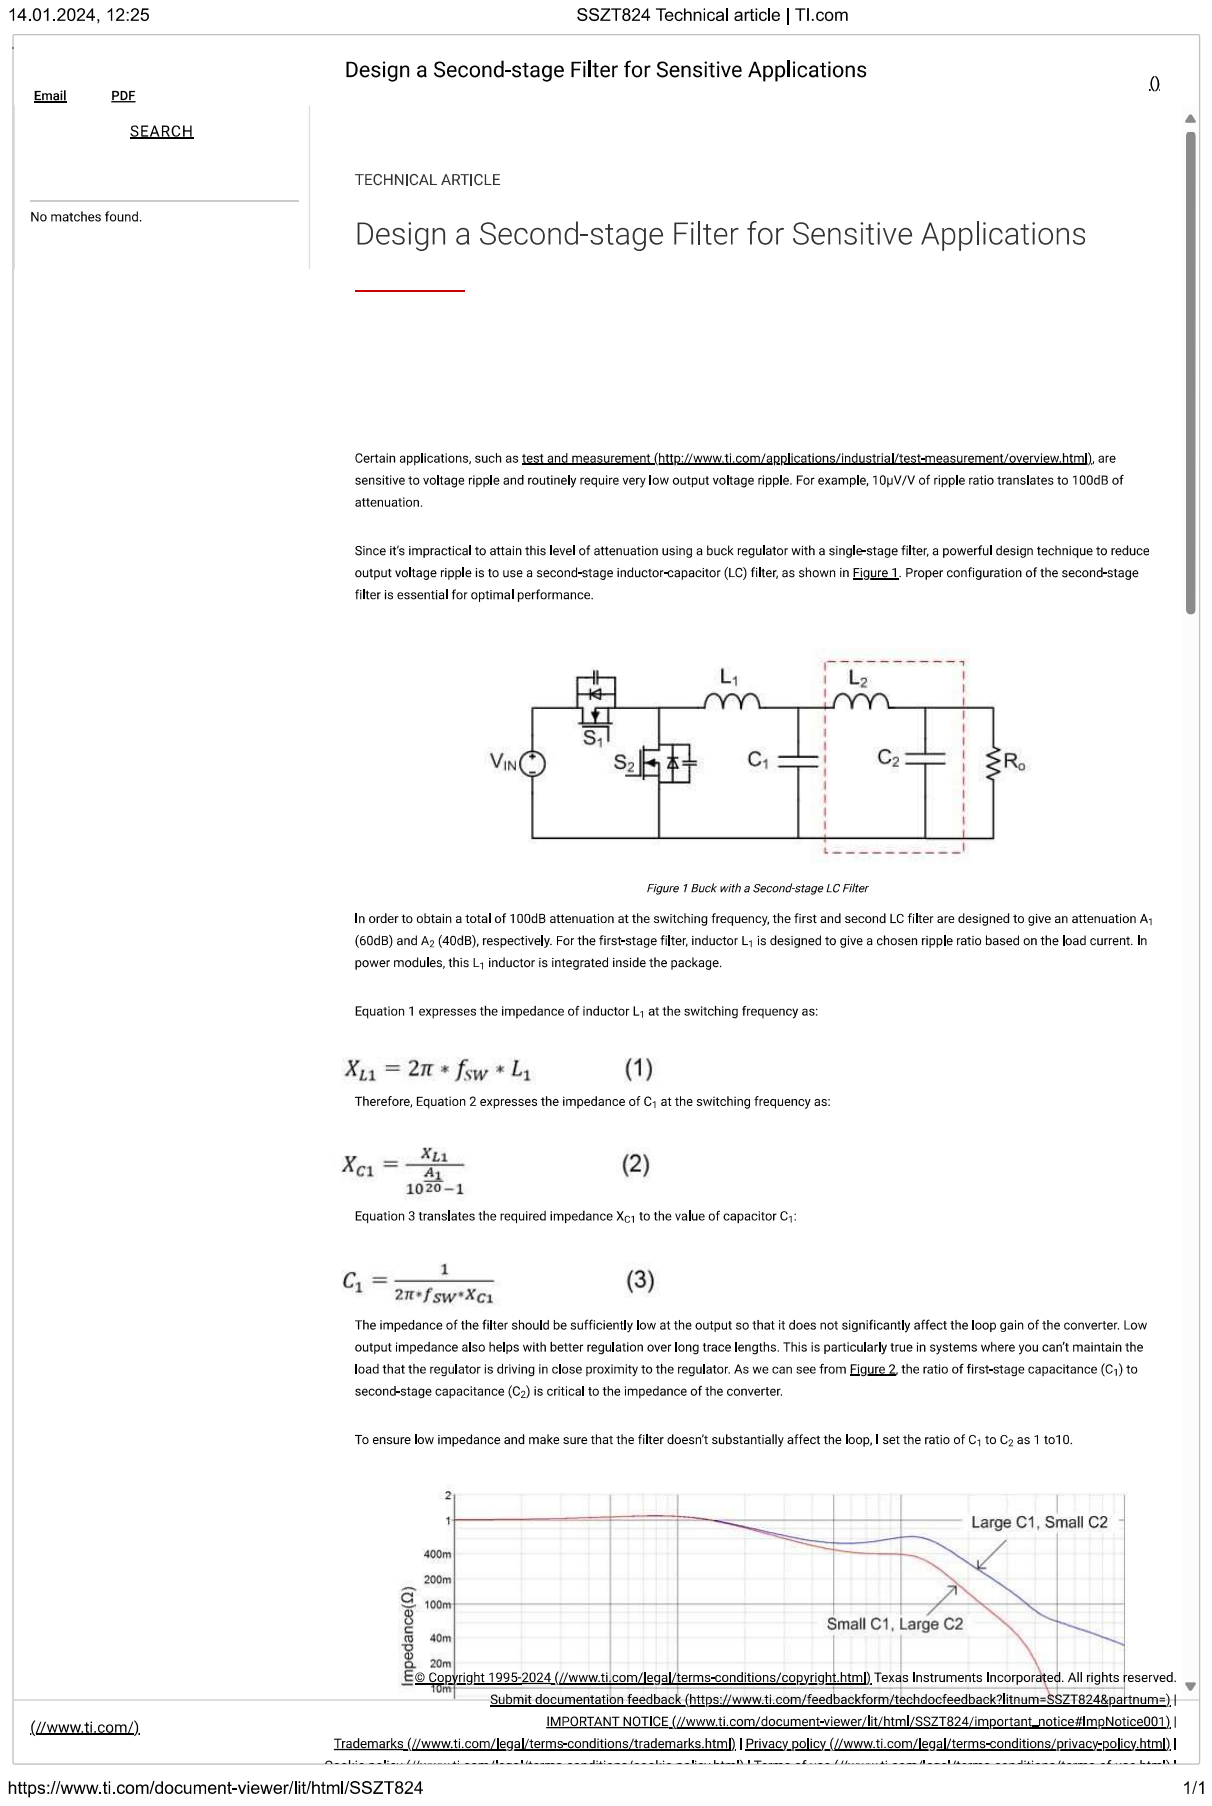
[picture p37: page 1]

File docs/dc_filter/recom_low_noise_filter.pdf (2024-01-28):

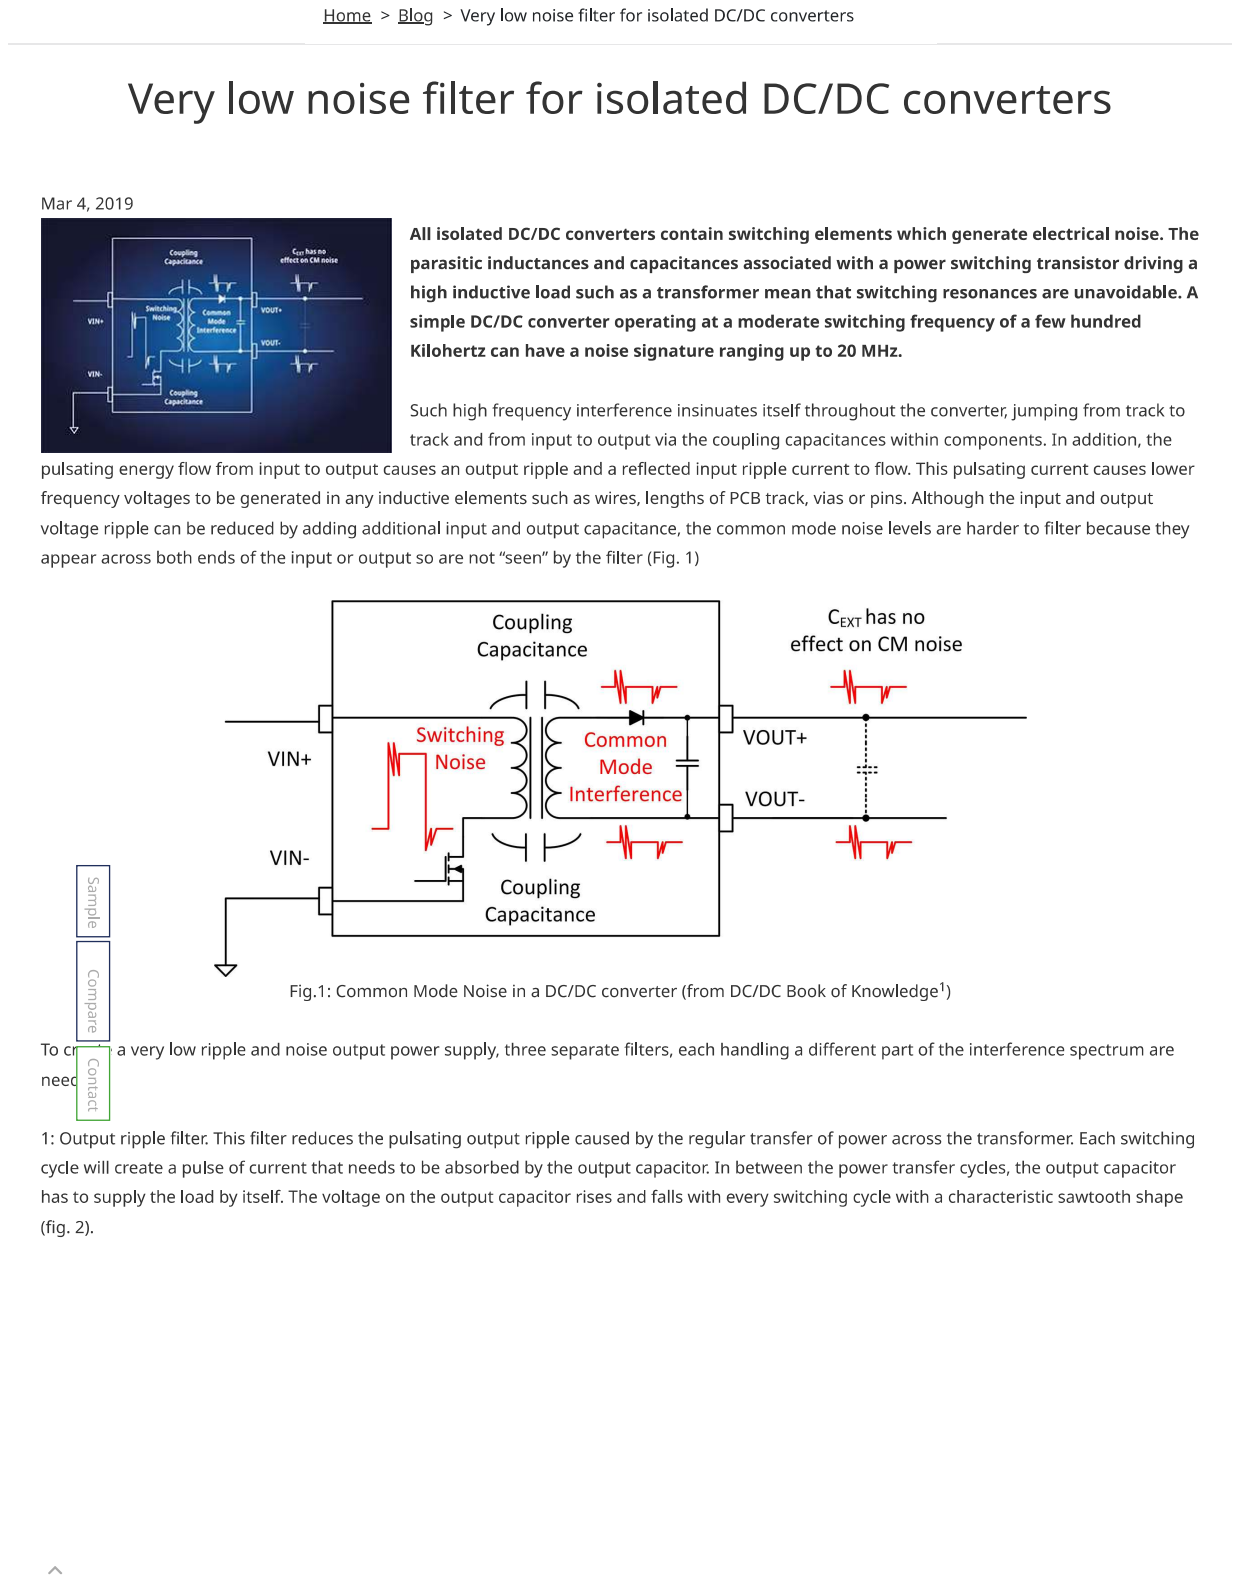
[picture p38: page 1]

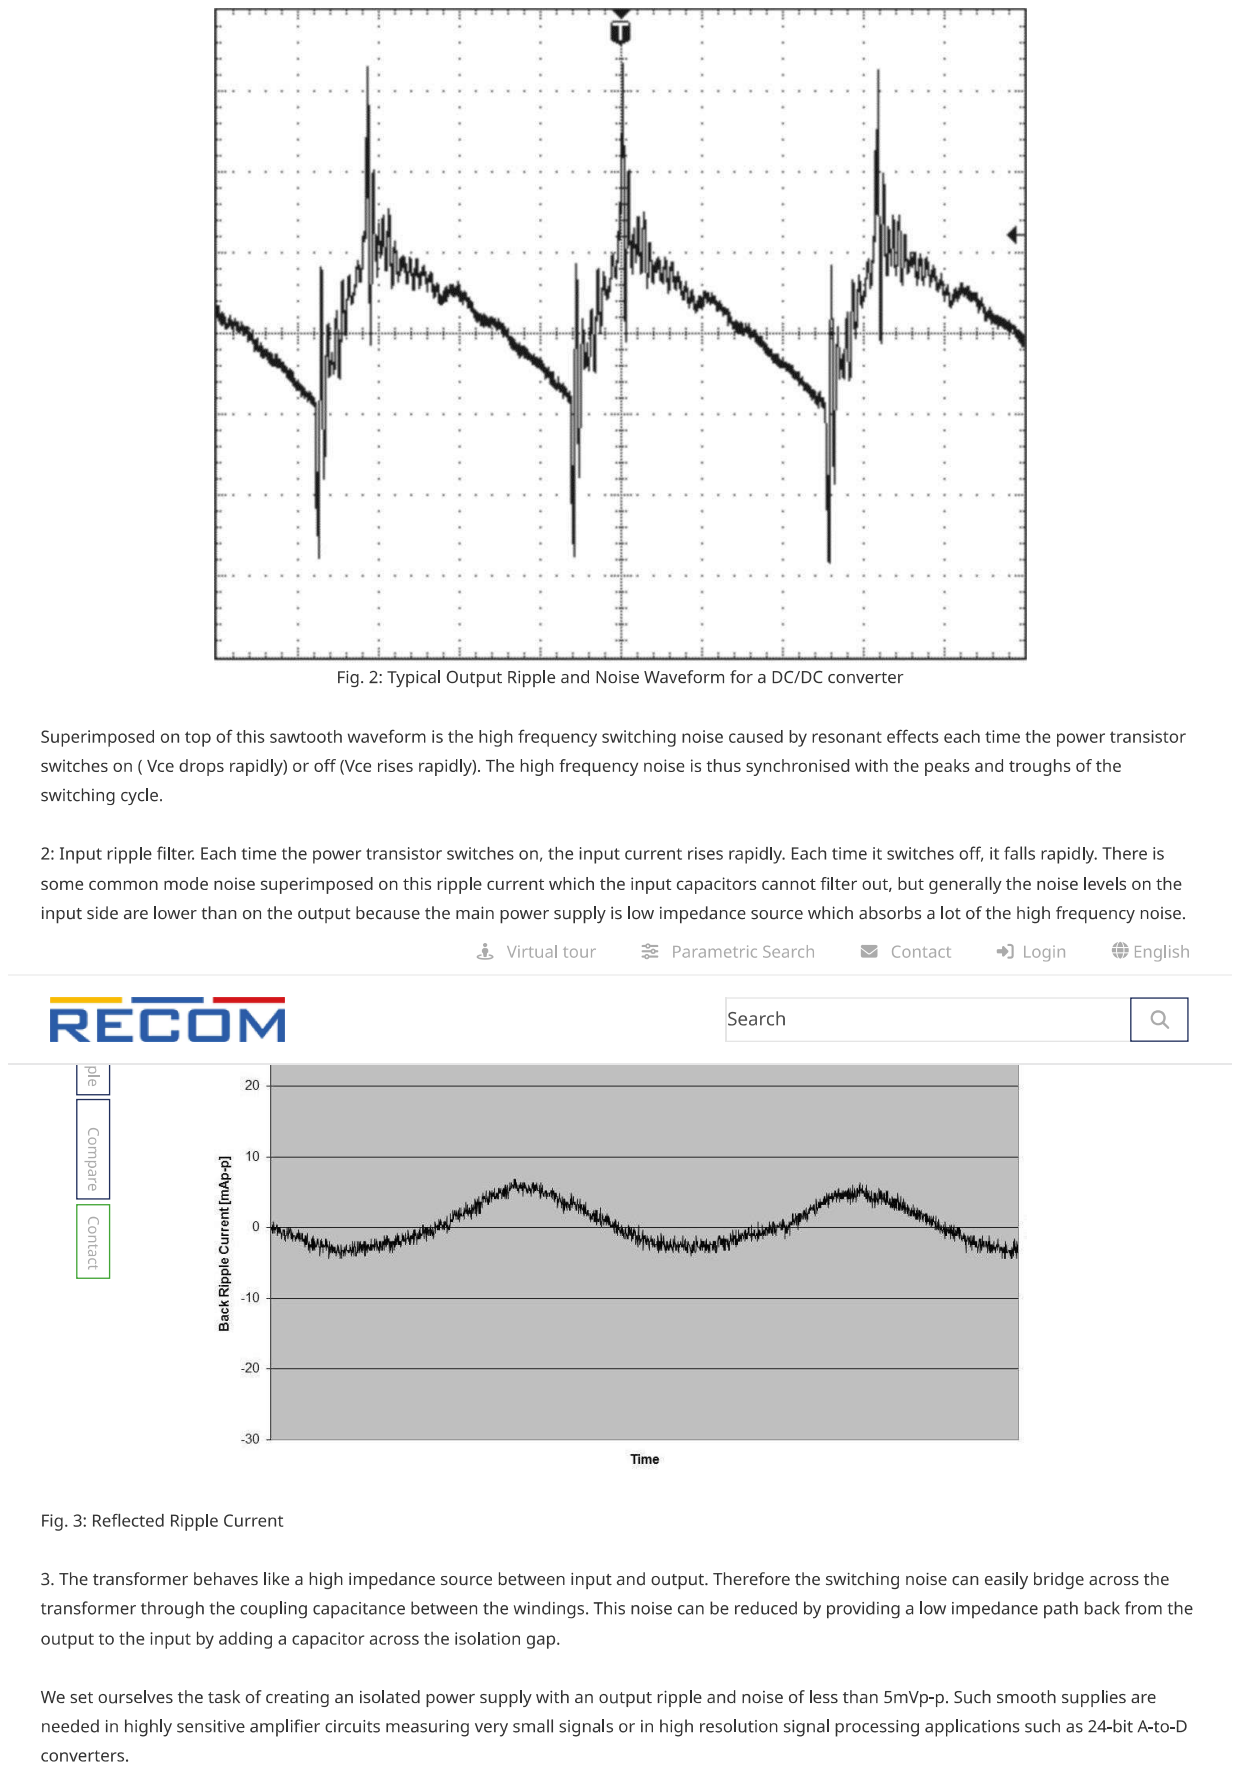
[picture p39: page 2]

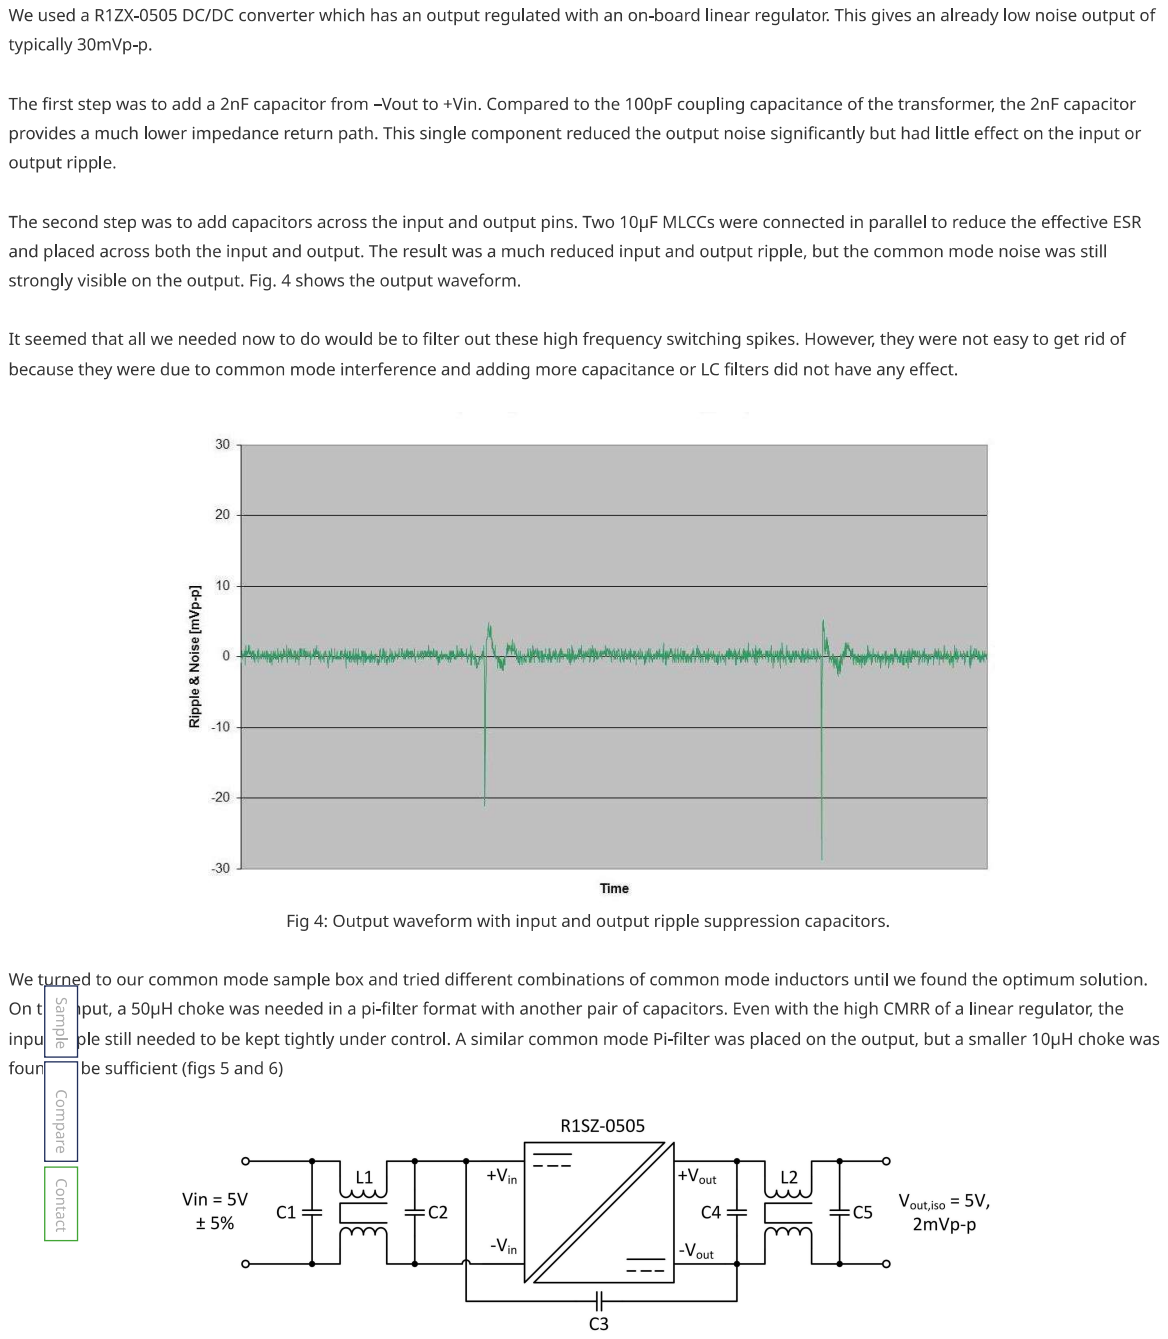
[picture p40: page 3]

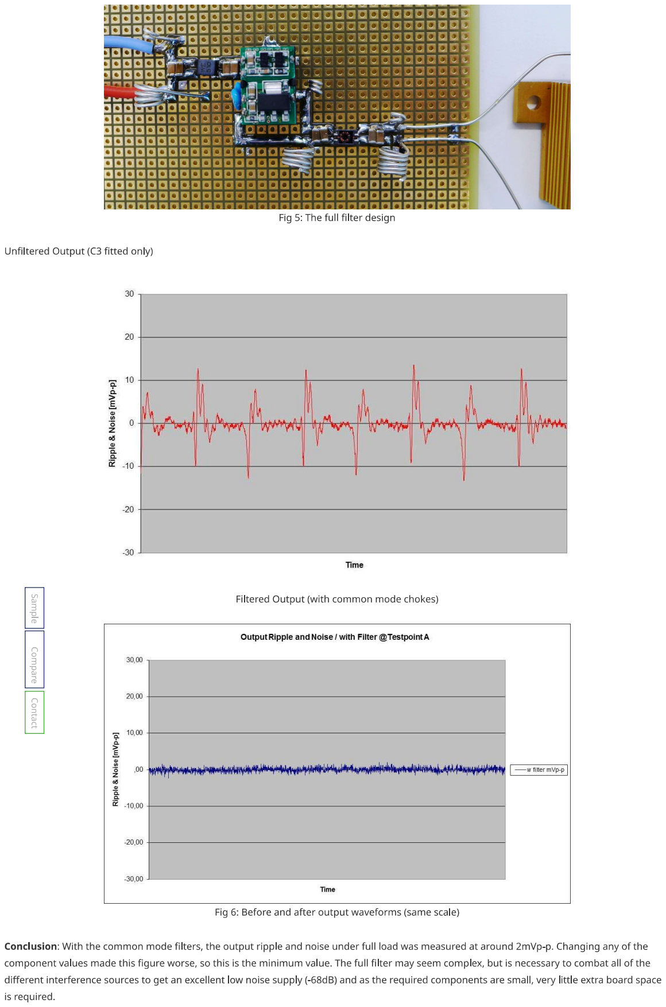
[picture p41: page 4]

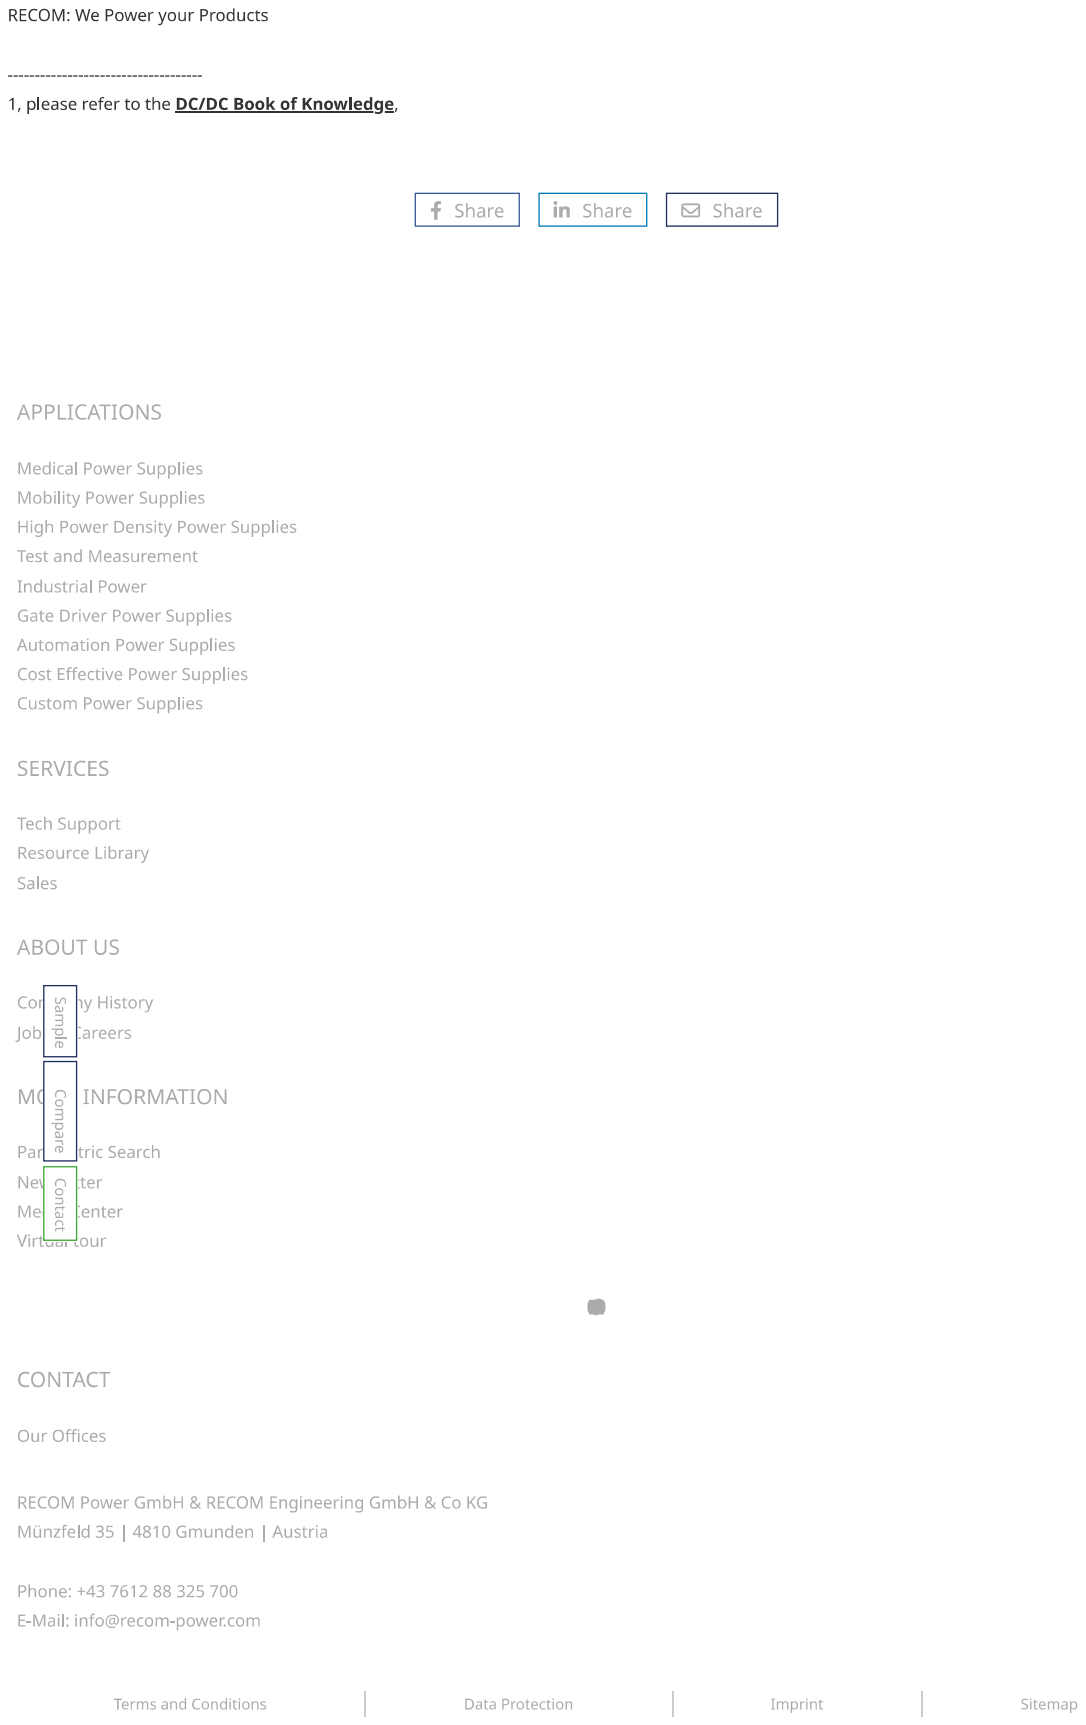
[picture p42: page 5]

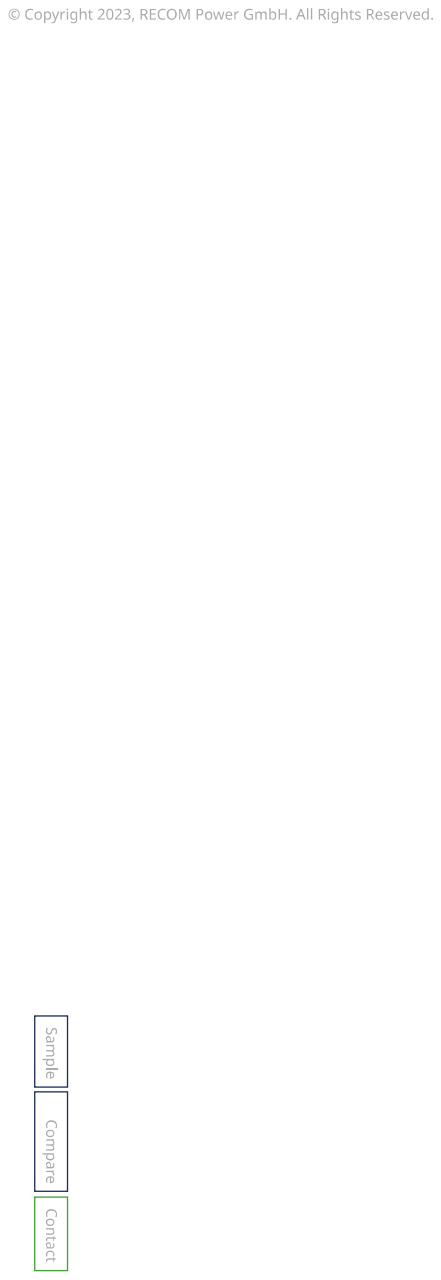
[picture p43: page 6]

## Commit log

2023-12-19 Schematics added to readme
2023-12-19 schematics dimensions reduced
2023-12-19 schematics dimensions changed
2023-12-23 diode model simulator added
2023-12-25 Working Script to Fit Diode Parameters to Actual Characteristics
2023-12-31 random wire impedance measurement added to readme
2024-01-07 readme re-written
    [crystal_radio_calculations.xlsx]
2024-01-07 schematics added
    [Detector_Radio_With_Optional_Amp.kicad_sch]
2024-01-07 files moved around
    [Detector_Radio_With_Optional_Amp.kicad_sch, crystal_radio_calculations.xlsx]
